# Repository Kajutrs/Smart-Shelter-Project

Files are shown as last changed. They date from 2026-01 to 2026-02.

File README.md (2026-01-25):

ჭკვიანი თავშესაფარი არის კომპლექსური IoT სისტემა, რომელიც შექმნილია ცხოველთა თავშესაფრების ავტომატიზაციისა და რეალურ დროში დისტანციური მონიტორინგისთვის. სისტემა აერთიანებს მაღალი სიმძლავრის თერმულ მართვას და დაბალი დაყოვნების ვიდეო ტრანსლაციას.

---

##  ძირითადი ფუნქციონალი

- **ავტომატური გათბობა:** DHT22 სენსორზე დაფუძნებული ინტელექტუალური თერმორეგულაცია.
- **ობიექტის დეტექცია:** VL53L0X (ToF) სენსორით ცხოველის არსებობის დადგენა მილიმეტრული სიზუსტით.
- **Real-Time Video:** WebRTC ტექნოლოგია წამზე ნაკლები (Sub-second) დაყოვნებისთვის.
- **Cloud Dashboard:** Go-ზე დაწერილი ბექენდი მონაცემთა ვიზუალიზაციისთვის.

---

## ტექნიკური არქიტექტურა

###  აპარატურა (Hardware)
- **MCU:** STM32L476RG (ARM Cortex-M4).
- **მონაცემების გადაცემა:** SIM800C (GSM/GPRS).
- **სენსორები:** - `VL53L0X` (Time-of-Flight) - **I2C ინტერფეისი**.
  - `DHT22` (Temp/Humidity) - **Single-Bus**.
- **კვება:** - `12V 10A` ცენტრალური კვება.
  - `88W` გამათბობელი ფირი.
  - `DROK Step-down` (12V to 5V) სტაბილიზაცია.

### პროგრამული ნაწილი (Software)
- **Firmware:** დაწერილია C-ზე.
- **ბექენდი:** Go (Golang) მაღალი წარმადობისთვის.
- **მედია სერვერი:** MediaMTX (RTSP to WebRTC Gateway).
- **სტრიმინგი:** UDP/SRTP პროტოკოლები.

---

##  ელექტრული პარამეტრები და პროტოკოლები

| კომპონენტი | ინტერფეისი | ძაბვა | დენის ძალა |
| :--- | :--- | :--- | :--- |
| **STM32L4** | Central MCU | 3.3V | < 100mA |
| **SIM800C** | UART | 5V | 2A (Peak) |
| **Heating Pad** | SSR Relay | 12V | **7.33A (88W)** |
| **VL53L0X** | I2C | 3.3V | < 20mA |

---

##  ვიდეო სტრიმინგის ჯაჭვი

1. **Capture:** Tapo C310 კამერა აგენერირებს RTSP ნაკადს.
2. **Gateway:** MediaMTX სერვერი იღებს ნაკადს და ახდენს მის ტრანსმუქსირებას.
3. **Signaling:** SDP (Offer/Answer) და ICE Candidates კავშირის დასამყარებლად.
4. **Latency:** WebRTC უზრუნველყოფს მინიმალურ დაყოვნებას NAT-ის გავლით.

---

##  გუნდი
- **თამარ ჯაში** - მიკროკონტროლერის პროგრამირება, სენსორების ინტეგრაცია და მართვის ალგორითმების შემუშავება.
- **გრიშა ტონერიანი** - სერვერული ინფრასტრუქტურის გამართვა, ვიდეო სტრიმინგის ოპტიმიზაცია და ქსელური კავშირის უზრუნველყოფა.
- **მარი დავლაძე** - ელექტრული სქემების დაპროექტება, ფიზიკური თავშესაფრის აწყობა. 

  ---

##  რეპოზიტორიის შიგთავსი 

ეს რეპოზიტორია შეიცავს პროექტისთვის საჭირო ყველა საკვანძო მასალას:

* ** ნახაზები (Designs):** სისტემის სავარაუდო სქემები და არქიტექტურული ნახაზები.
* ** Excel დოკუმენტაცია:** * **განტის დიაგრამა** (პროექტის ვადები და ფაზები).
    * **ბიუჯეტი & კომპონენტები** (დეტალური ფასები და ლინკები).
    * **მოვალეობების ცხრილი** (გუნდის წევრებს შორის განაწილებული ფუნქციები).
* ** ლიტერატურა:** გამოყენებული წყაროები და მონაცემთა ფურცლები (Datasheets).
* ** სახელმძღვანელო:** მომხმარებლის დეტალური ინსტრუქცია სისტემის გამართვისა და ექსპლუატაციისთვის.
* ** კოდის ნაწყვეტები:** პროექტის ყველაზე კრიტიკული ალგორითმებისა და ფუნქციების იმპლემენტაცია.
* ** პროექტის ვებსაიტი:** ბმული პროექტის შესახებ შექმნილ პლატფორმაზე.

---

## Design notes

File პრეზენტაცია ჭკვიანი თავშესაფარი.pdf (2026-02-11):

ილიას სახელმწიფო უნივერსიტეტი

### დამამთავრებელი კურსის დიზაინის პროექტი A (https://argus.iliauni.edu.ge/ka/student/courses/117972/groups)

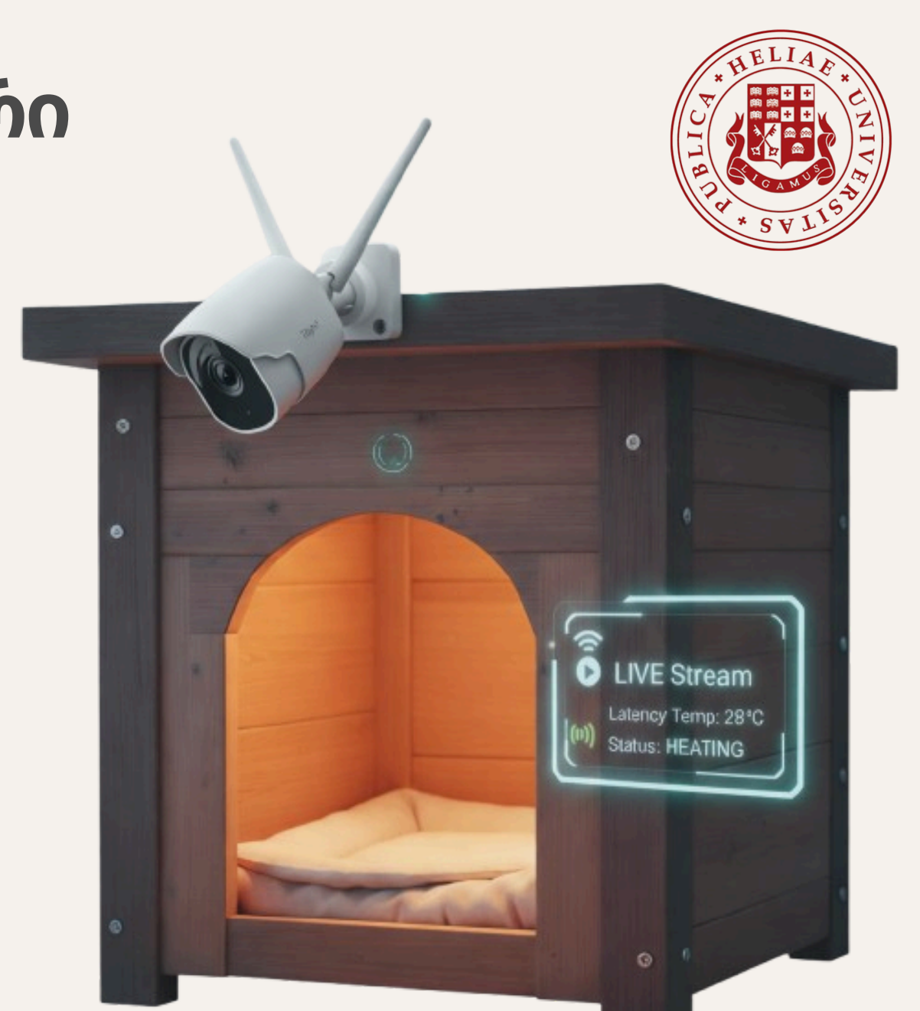
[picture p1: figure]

# ჭკვიანი თავშესაფარი

2026

თამარ ჯაში, გრიშა ტონერიანი,

## მარი დავლაძე

# პრობლემა (1)

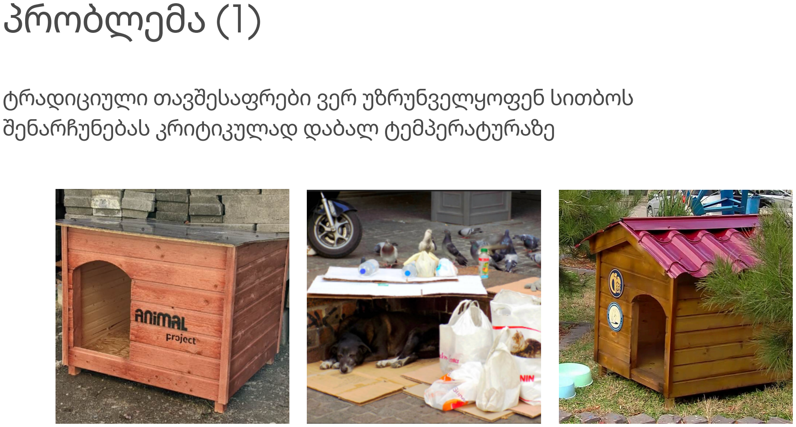
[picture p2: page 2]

### ტრადიციული თავშესაფრები ვერ უზრუნველყოფენ სითბოს შენარჩუნებას კრიტიკულად დაბალ ტემპერატურაზე

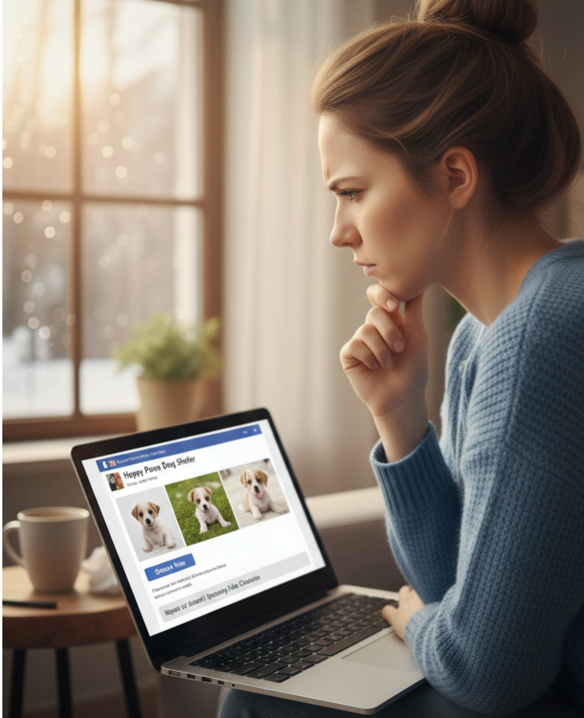
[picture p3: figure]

# პრობლემა(2)

### დონორს არ აქვს საშუალება გადაამოწმოს, რეალურად მიაღწია თუ

არა მისმა დახმარებამ ცხოველამდე.

გ

ა

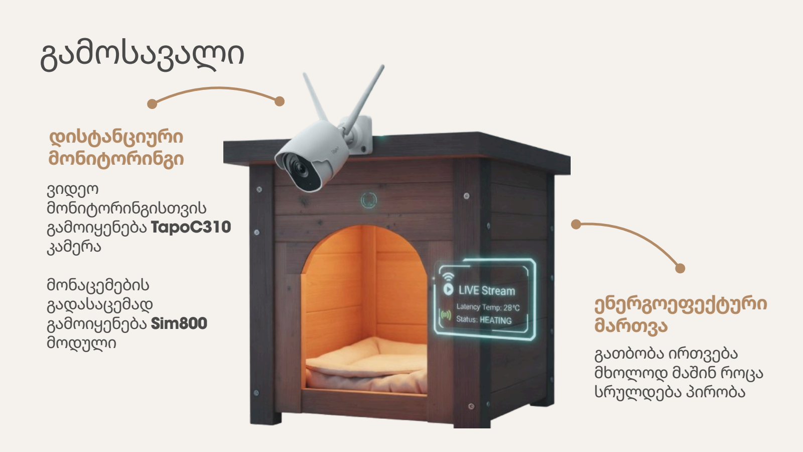
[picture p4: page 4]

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
## ბლოკ - სქემა

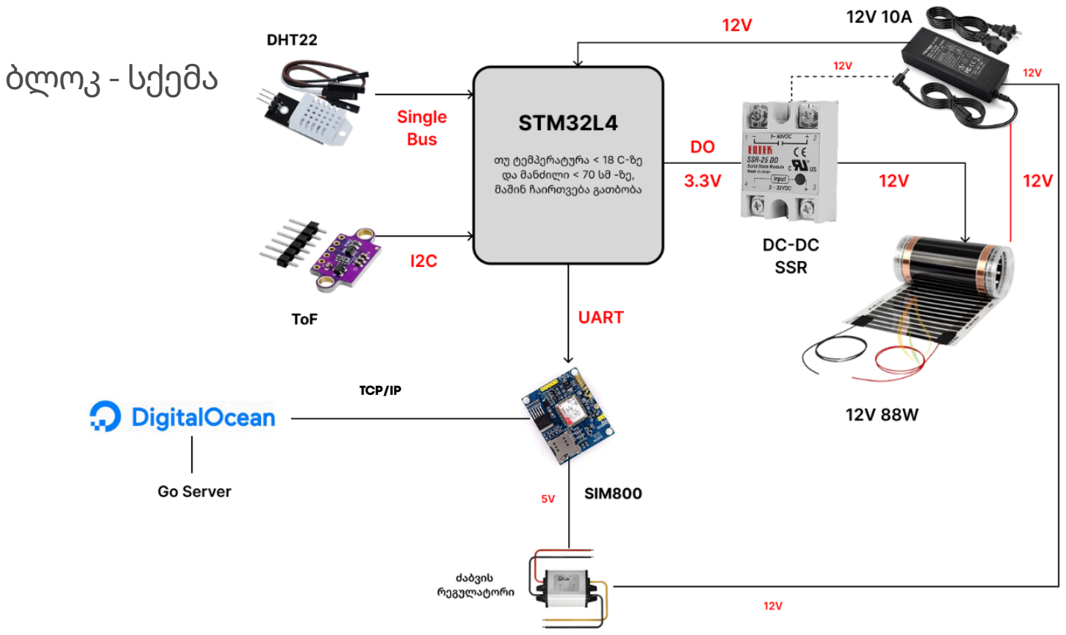
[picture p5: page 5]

TCP/IP

## სისტემის მართვისა და მონაცემთა გადაცემის ალგორითმი

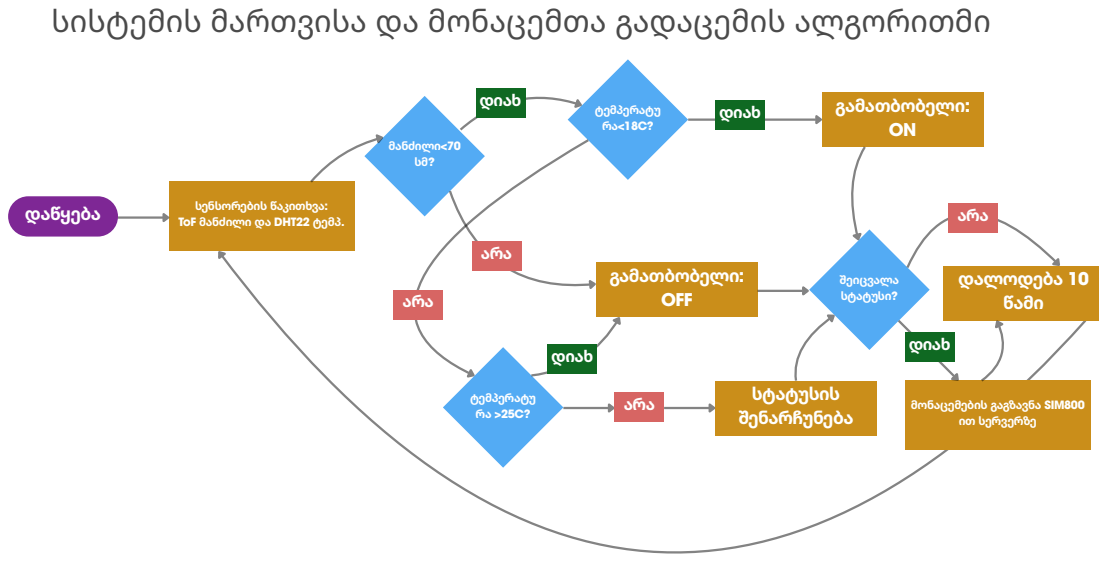
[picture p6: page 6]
მონაცემების გაგზავნა SIM800 ით სერვერზე; გამათბობელი:; დალოდება 10 წამი; სტატუსის შენარჩუნება; მანძილი<70 სმ?; ტემპერატუ რა >25C?; შეიცვალა სტატუსი?; ტემპერატუ რა<18C?; დაწყება; დიახ; არა

დიახ

სენსორების წაკითხვა:
ToF მანძილი და DHT22 ტემპ.

გამათბობელი: | OFF

არა

FPU უზრუნველყოფს სენსორების მონაცემების სწრაფ და ზუსტ
დამუშავებას.

Cortex - M4F

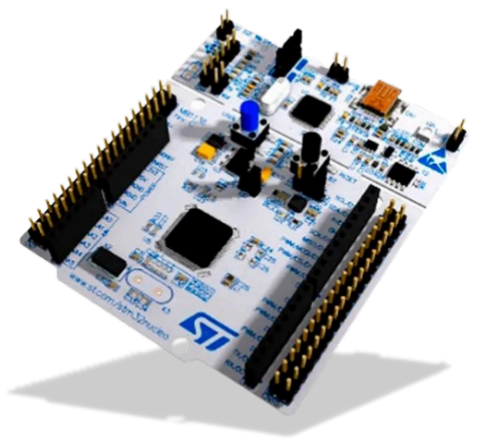
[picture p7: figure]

ენერგოეფექტურობა: L4 სერია

მუშაობს 3.3V ძაბვაზე, რაც თავსებადია სხვა მოწყობილობებთან

როდესაც თავშესაფარი ცარიელია, MCU გადადის Sleep/Stop რეჟიმში ენერგიის მინიმალური
მოხმარებისთვის.

### 3.3 V Logic

# მიკროკონტროლერი

STM32L476RG (https://www.amazon.com/STM32-Nucleo-64-Development-STM32L476RG-NUCLEO-L476RG/dp/B01IO3N646)

# მანძილის სენსორი

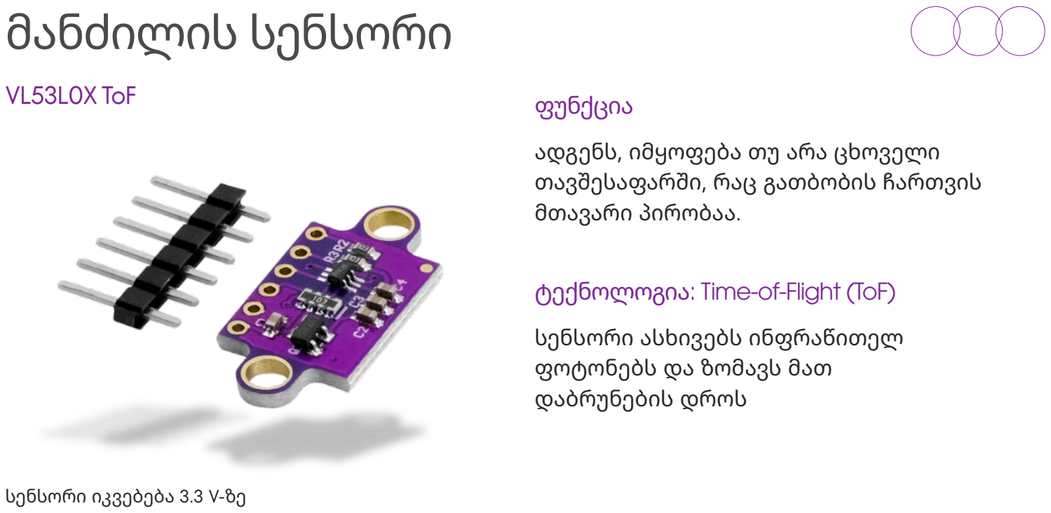
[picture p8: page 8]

ადგენს, იმყოფება თუ არა ცხოველი თავშესაფარში, რაც გათბობის ჩართვის მთავარი პირობაა.

სენსორი ასხივებს ინფრაწითელ ფოტონებს და ზომავს მათ
დაბრუნების დროს

სენსორი იკვებება 3.3 V-ზე

ფუნქცია

ტექნოლოგია: Time-of-Flight (ToF)

### VL53L0X ToF (https://www.temu.com/ul/kuiper/un9.html?subj=goods-un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)

# მანძილის ფორმულა

## D=(c*t)/2

## D- მანძილი C- მუდმივა, სინათლის სიჩქარე(დაახლოებით 3 * 10^8) t- დრო

## 2-ზე გაყოფა საჭიროა, რადგან სინათლემ გაიარა ორმაგი მანძილი - წინ და უკან

# გათბობის ლოგიკა

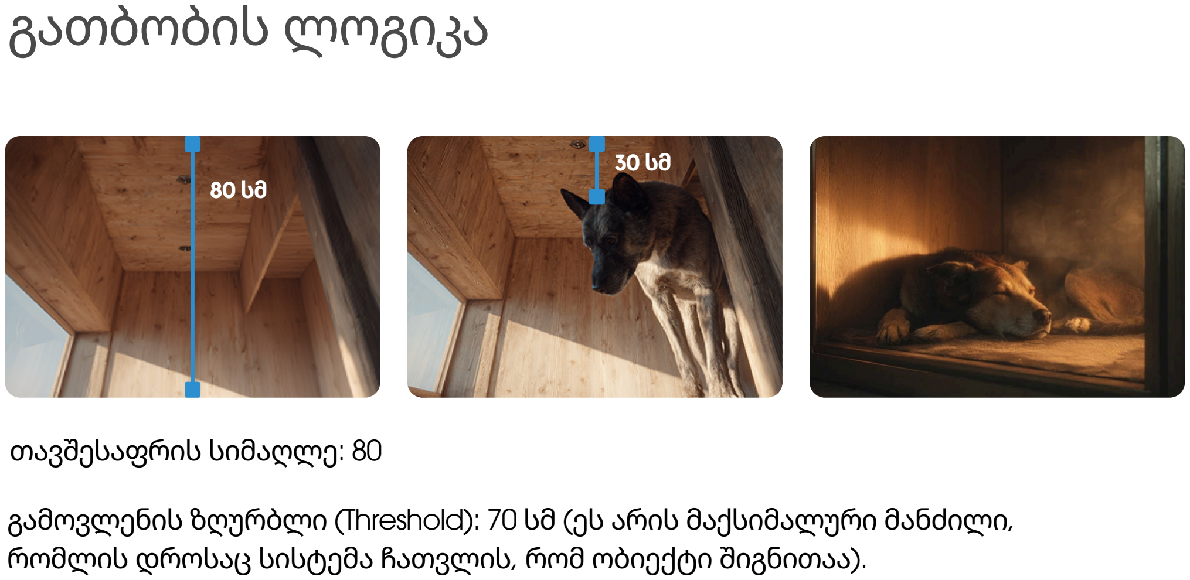
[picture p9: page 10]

### 80 სმ

### 30 სმ

თავშესაფრის სიმაღლე: 80 სმ\ სმtext{ სმ}$.

გამოვლენის ზღურბლი (Threshold): 70 სმ (ეს არის მაქსიმალური მანძილი, რომლის დროსაც სისტემა ჩათვლის, რომ ობიექტი შიგნითაა).

# თერმოსტატული კონტროლი

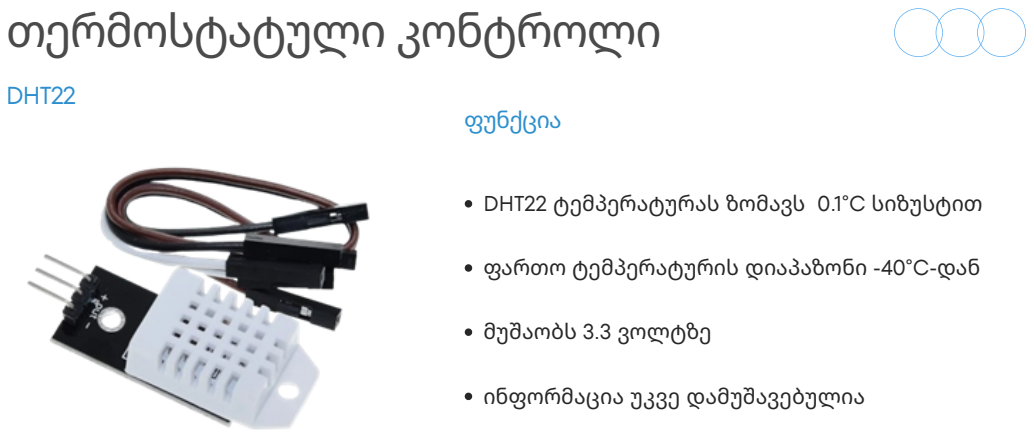
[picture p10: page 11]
ფუნქცია; DHT22; მუშაობს 3.3 ვოლტზე

DHT22 ტემპერატურას ზომავს 0.1°C სიზუსტით

ფართო ტემპერატურის დიაპაზონი -40°C-დან

ინფორმაცია უკვე დამუშავებულია

SIM800C GSM მოდული (https://www.amazon.com/EC-Buying-Quad-Band-Integrated-Transmission/dp/B0B64X81LD)
ფუნქცია

# მონაცემების გადაცემა

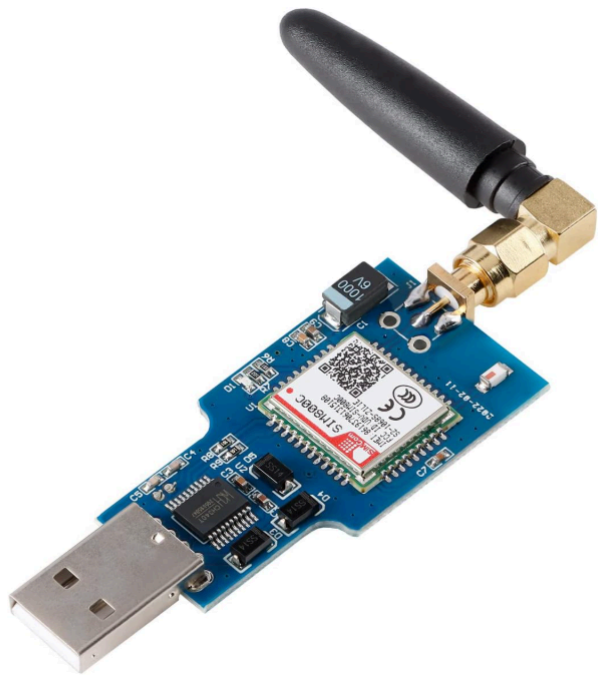
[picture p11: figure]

SIM800C მოდულის მთავარი ფუნქციაა მონაცემთა ტრანსპორტირება. მას შემდეგ, რაც STM32L4 დაამუშავებს სენსორების ინფორმაციას, SIM800C ამ მონაცემებს GPRS არხის მეშვეობით აგზავნის სერვერზე

# გათბობის ფირი

12V Heating Film (https://www.alibaba.com/product-detail/12V-24V-110V-220V-Thermostat-Graphene_60783773014.html) | 12V 10A ადაპტერი
12V

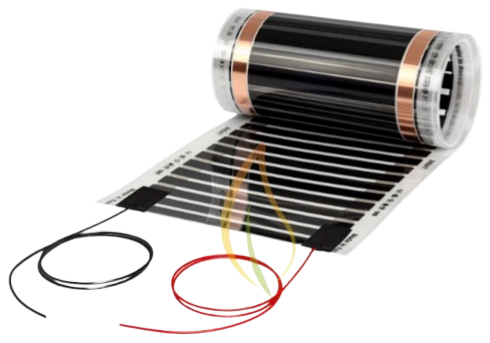
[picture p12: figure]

| 12 ვოლტზე მომუშავე 88 ვატის სიმძლავრის ფირი
| ფირა მაქსიმუმ 45 C - მდე ხურდება

უსაფრთხოების და ძაბვის არჩევანი

# არქიტექტურა და თბოიზოლაცია

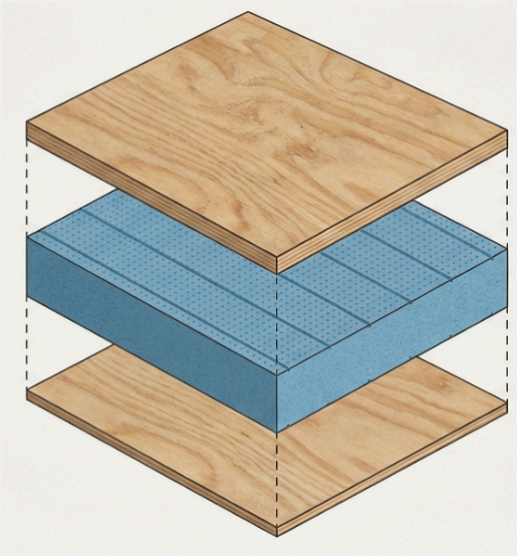
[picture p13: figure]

გარე ფენა

იზოლაცია

შიდა ფენა

12მმ FSF ფანერა

50მმ XPS

8-10 მმ FK ფანერა

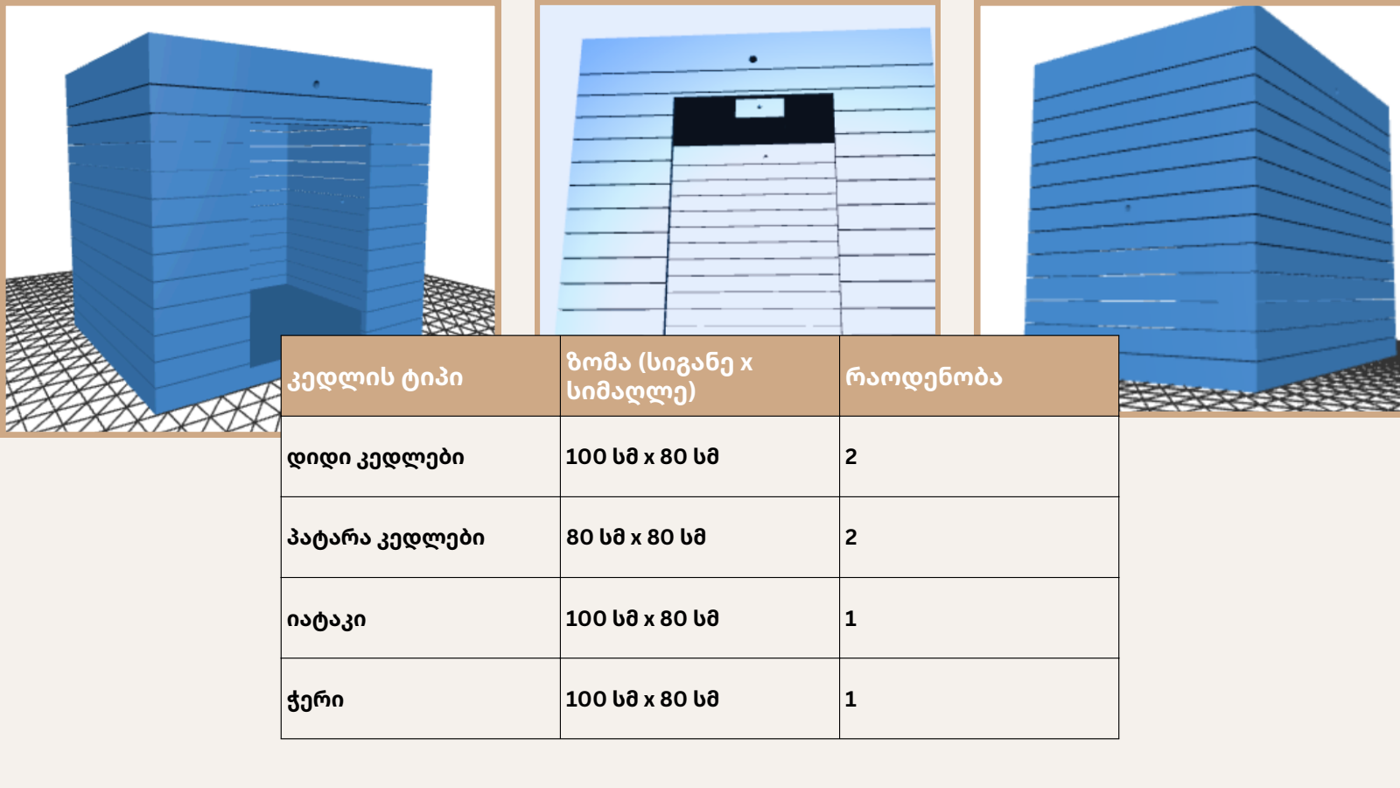
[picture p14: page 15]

კედლის ტიპი | ზომა (სიგანე x სიმაღლე) | რაოდენობა
დიდი კედლები | 100 სმ x 80 სმ | 2
პატარა კედლები | 80 სმ x 80 სმ | 2
იატაკი | 100 სმ x 80 სმ | 1
ჭერი | 100 სმ x 80 სმ | 1

# კამერა

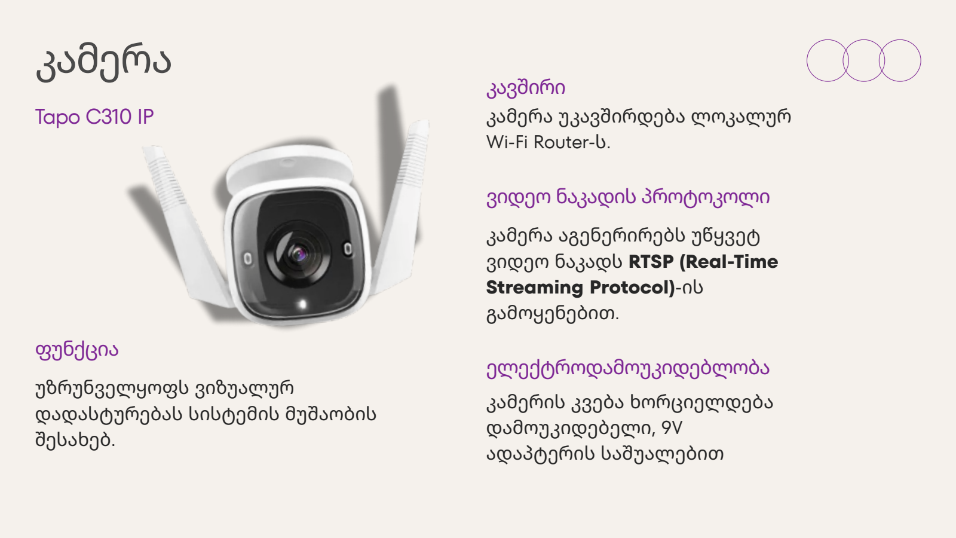
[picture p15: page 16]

უზრუნველყოფს ვიზუალურ
დადასტურებას სისტემის მუშაობის შესახებ.

ფუნქცია

კამერა უკავშირდება ლოკალურ Wi-Fi Router-ს.

კამერა აგენერირებს უწყვეტ
ვიდეო ნაკადს RTSP (Real-Time Streaming Protocol)-ის
გამოყენებით.

კამერის კვება ხორციელდება
დამოუკიდებელი, 9V
ადაპტერის საშუალებით

კავშირი

ვიდეო ნაკადის პროტოკოლი

ელექტროდამოუკიდებლობა

Tapo C310 IP (https://alta.ge/chkviani-kamera/tp-link-tapo-c310-outdoor-security-wi-fi-camera-p22565)

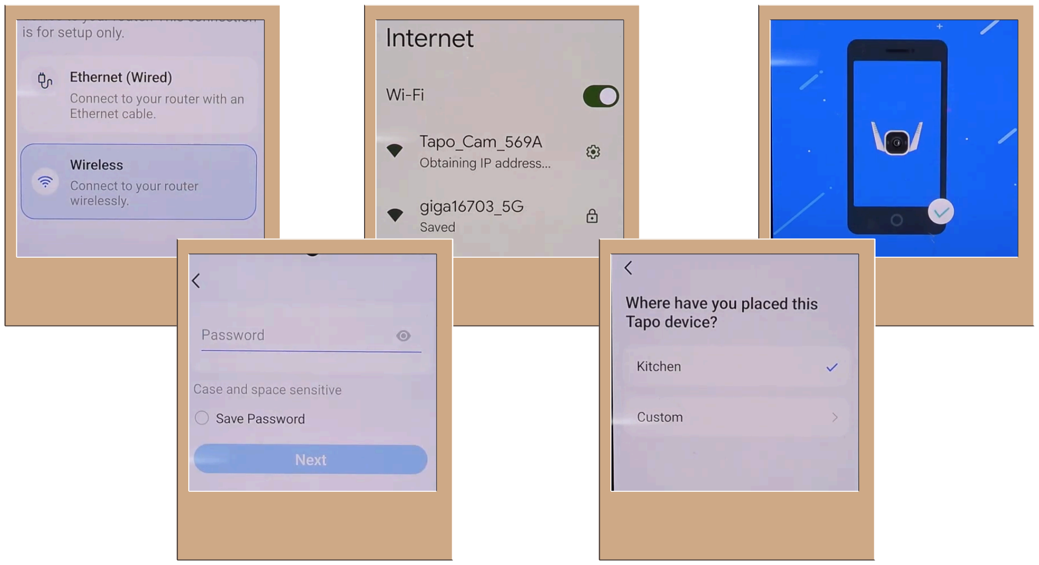
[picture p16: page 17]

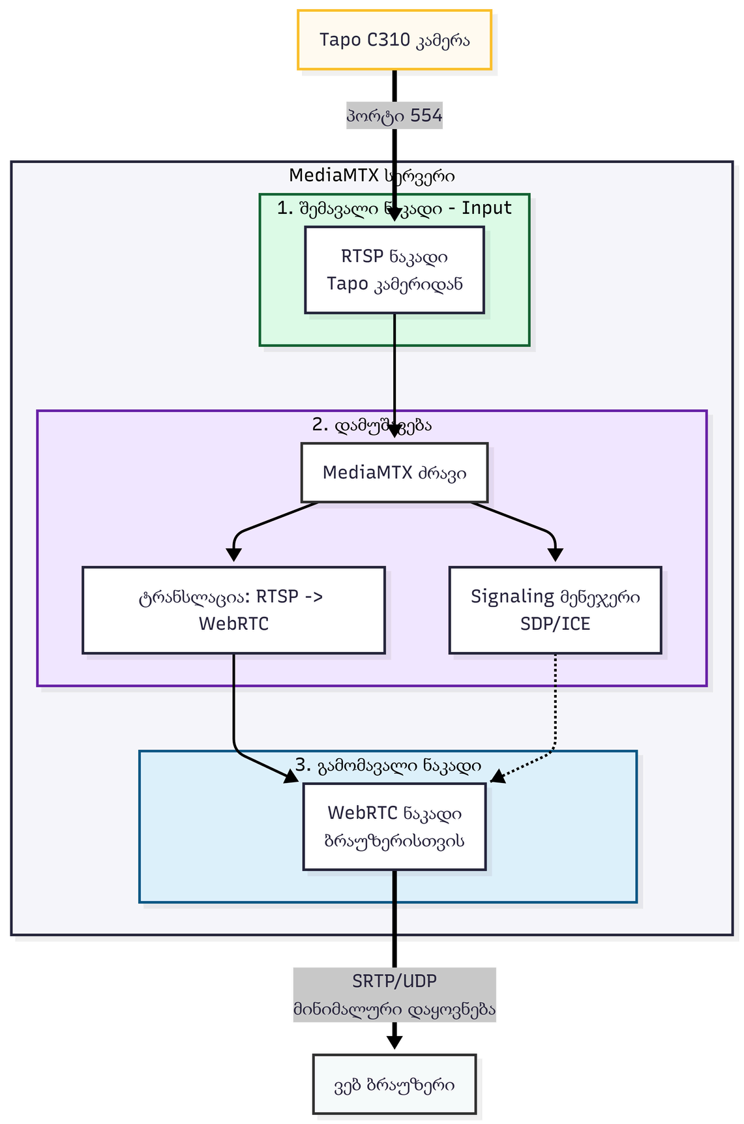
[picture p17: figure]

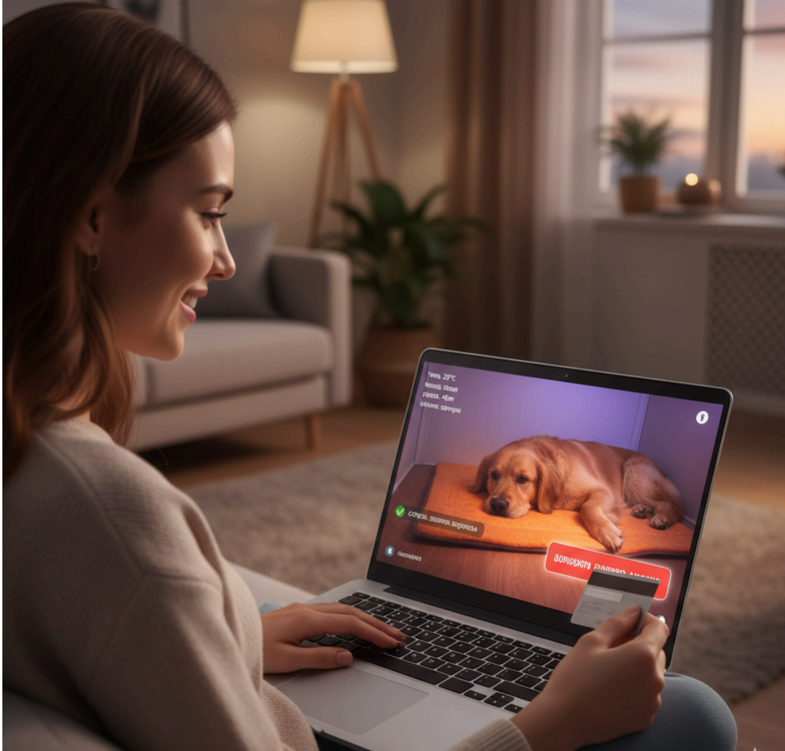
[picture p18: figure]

# დონაცია

გამჭვირვალობა: მომხმარებელი ხედავს ზუსტ ტემპერატურას და ცხოველის მდგომარეობას, რაც ნდობას აჩენს.

ემოციური კავშირი: RTSP
სტრიმინგი საშუალებას აძლევს ადამიანს, გახდეს პროექტის
ნაწილი მსოფლიოს ნებისმიერი წერტილიდან.

განტის დიაგრამა (https://github.com/Kajutrs/Smart-Shelter-Project/blob/main/%E1%83%94%E1%83%A5%E1%83%A1%E1%83%94%E1%83%9A%E1%83%98%E1%83%A1%20%E1%83%A4%E1%83%90%E1%83%98%E1%83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)

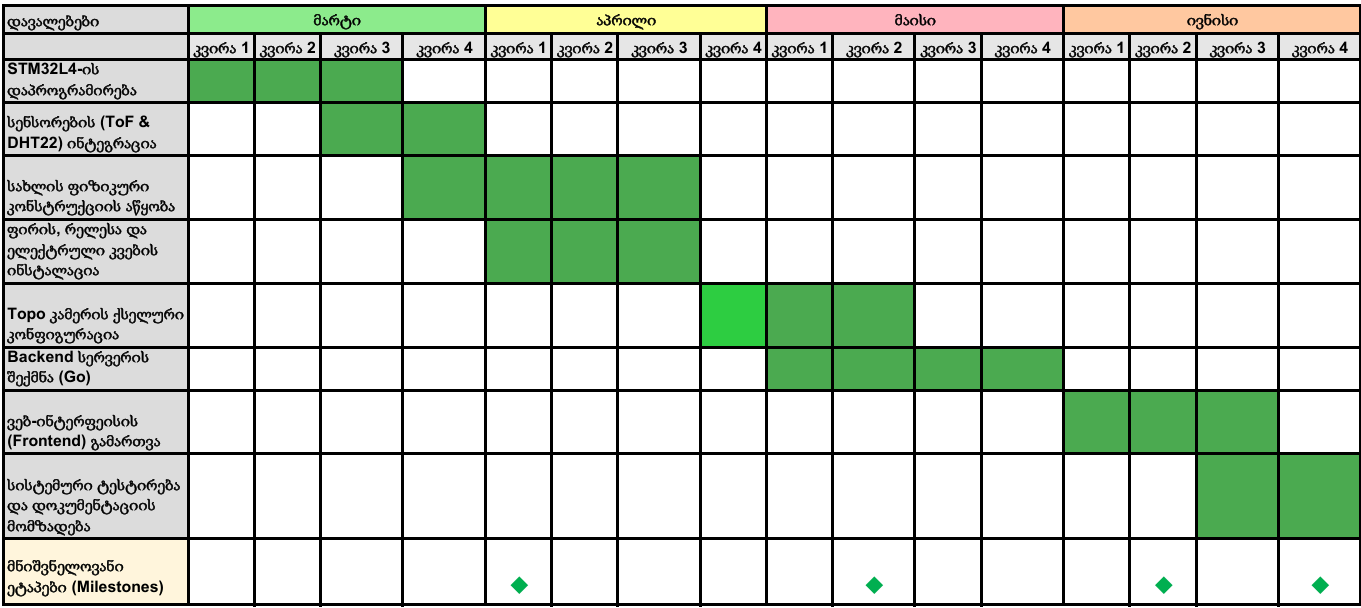
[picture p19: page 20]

მოვალეობები | სტუდენტები
STM32L4 მიკროკონტროლერის დაპროგრამება | თამარ ჯაში
ToF და DHT22 სენსორების ინტეგრაცია | თამარ ჯაში
კომუნიკაციის მოდულის (SIM800C) გამართვა | თამარ ჯაში
თავშესაფრის ფიზიკური აწყობა | მარი დავლაძე
გათბობის ფენის ინსტალაცია | მარი დავლაძე
ელექტრონიკის დაცული განყოფილების მოწყობა | მარი დავლაძე
Tapo კამერის ქსელური კონფიგურაცია | გრიშა ტონერიანი
Backend API-ს დაწერა | გრიშა ტონერიანი
Frontend ინტერფეისის აწყობა | თამარ ჯაში
Digital Ocean სერვერის მომზადება | გრიშა ტონერიანი

კომპონენტები/ბიუჯეტი (https://github.com/Kajutrs/Smart-Shelter-Project/blob/main/%E1%83%94%E1%83%A5%E1%83%A1%E1%83%94%E1%83%9A%E1%83%98%E1%83%A1%20%E1%83%A4%E1%83%90%E1%83%98%E1%83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)

კომპონენტი | ფასი
STM32L476RG | 64.70 ლარი
VL53L0X ToF | 6.29 ლარი
DHT22 | 2.27 ლარი
TP-Link Tapo C310 Wi-Fi | 169 ლარი
SIM800C GSM | 40.09 ლარი
ადაპტერი 12V 10A | 32.81 ლარი
გათბობის ფირი 12V | 12.51 ლარი
რელე DC DC SSR | 6.75 ლარი
Digital Ocean სერვერი | 15.99 ლარი

იხ. სრული სია ლინკზე (https://github.com/Kajutrs/Smart-Shelter-Project/blob/main/%E1%83%94%E1%83%A5%E1%83%A1%E1%83%94%E1%83%9A%E1%83%98%E1%83%A1%20%E1%83%A4%E1%83%90%E1%83%98%E1%83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)

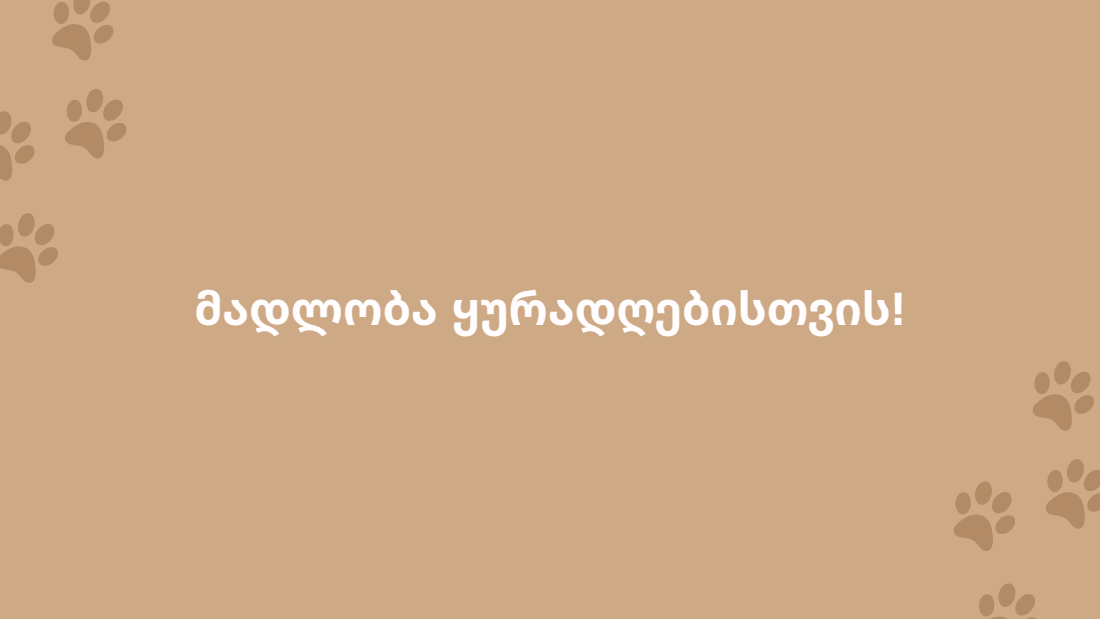
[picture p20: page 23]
მადლობა ყურადღებისთვის!

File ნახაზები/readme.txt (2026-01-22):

1. კლიმატ-კონტროლისა და სენსორული მართვის ბლოკსქემა
ეს სქემა წარმოადგენს სისტემის „ტვინს“ და ასახავს ფიზიკურ კავშირებს მიკროკონტროლერსა და პერიფერიულ მოწყობილობებს შორის

2. სისტემის მართვისა და მონაცემთა გადაცემის ალგორითმი
დიაგრამა აღწერს თავშესაფრის ავტონომიურ სამუშაო ციკლს

3. სისტემის ფუნქციური დიაგრამა და მონაცემთა ნაკადი
ასახავს ინფორმაციის მოძრაობის სრულ ჯაჭვს ლოკალური სენსორებიდან ღრუბლოვან პლატფორმამდე

4. MediaMTX მუშაობის სქემა
ეს დიაგრამა აღწერს ვიზუალური ქვესისტემის მუშაობას, რომელიც დაფუძნებულია დაბალი დაყოვნების ტექნოლოგიებზე

5. RTSP ნაკადის გადაცემა 
ეს დიაგრამა არწერს თუ როგორ შეიძლება Tapo C310 კამერის RTSP ნაკადის გარდაქმნა WebRTC‑ზე MediaMTX - ის გამოყენებით, რათა მომხმარებელს ჰქონდეს პირდაპირი წვდომა ბრაუზერიდან.

6. 3D ფაილი
ეს ფაილი წარმოადგენს „ჭკვიანი თავშესაფრის“ ფიზიკურ მოდელს

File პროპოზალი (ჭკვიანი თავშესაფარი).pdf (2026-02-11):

## ილიას სახელმწიფო უნივერსიტეტი

ბიზნესის, ტექნოლოგიების და განათლების ფაკულტეტი

ტექნოლოგიების სკოლა

# “ჭკვიანი თავშესაფარი”

წინადადება

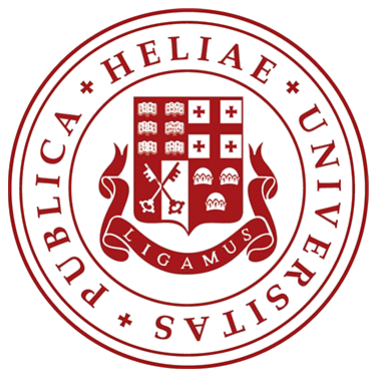
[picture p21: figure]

## გუნდის წევრები

თამარ ჯაში, გრიშა ტონერიანი, მარი დავლაძე

კომპიუტერული ინჟინერიის საბაკალავრო პროგრამა

სენიორ დიზაინის პროექტი A

პროექტის ხელმძღვანელები: პროფ. დავით ჩხაიძე, პროფ. გიორგი მოდებაძე

2026
თბილისი, საქართველო

## სარჩევი

## აბსტრაქტი

მოცემული პროექტი ზამთრის პირობებში, უპატრონო ცხოველთა გადარჩენის აშკარა საჭიროებას IoT-ინტეგრირებული „ჭკვიანი თავშესაფრის“ დაპროექტების გზით გადაჭრის. საინჟინრო თვალსაზრისით, გამოწვევა მდგომარეობს სტატიკური გათბობის სისტემების დაბალ ეფექტურობაში, რაც იწვევს ენერგიის არამიზნობრივ ხარჯვას თავშესაფრის ცარიელ მდგომარეობაში ყოფნისას. პროექტის ფარგლებში შეიქმნება ჰიბრიდული (Hardware & Software) სისტემა, რომლის ძირითადი იდეაა სენსორებზე დაფუძნებული ავტომატური გარემოს მართვა და რეალურ დროში ვიდეომონიტორინგის ინტეგრაცია. ტექნიკური გადაწყვეტა ინოვაციურია Time-of-Flight (ToF) ლაზერული სენსორის გამოყენებით სივრცის მუდმივი სკანირებისთვის, რაც უზრუნველყოფს ობიექტის არსებობის ზუსტ დეტექციას და გამორიცხავს გათბობის სისტემის ფუჭ მუშაობას. მეთოდოლოგია დაეფუძნება STM32L4 მიკროკონტროლერს, SIM800C GSM მოდულსა და სპეციალიზებულ ღრუბლოვან სერვერს მონაცემთა ნაკადების დასამუშავებლად. პროექტის საბოლოო შედეგი იქნება სრულად ფუნქციონალური პროტოტიპი და დისტანციური მონიტორინგის ვებ-პლატფორმა, რომელიც მომხმარებელს რეალურ დროში ვიდეოტრანსლაციის ნახვის, ტელემეტრიული მონაცემების გაცნობისა და ინტეგრირებული დონაციის სისტემით სარგებლობის შესაძლებლობას მისცემს. პროექტის პრაქტიკული და სოციალური მნიშვნელობა კი ცხოველებზე ზრუნვის მდგრადი მოდელის შექმნაში მდგომარეობს, რაც საზოგადოებას ზრუნვის პროცესში გამჭვირვალე ჩართულობის მექანიზმს შესთავაზებს.

## შესავალი

ურბანულ გარემოში უპატრონო ცხოველების გადარჩენა, განსაკუთრებით ზამთრის პერიოდში, სერიოზულ სოციალურ და საინჟინრო გამოწვევას წარმოადგენს. ამ პრობლემის გადასაჭრელად დღეს არსებული მიდგომები მნიშვნელოვან შეზღუდვებს შეიცავს. კერძოდ, პასიური თავშესაფრები ვერ უზრუნველყოფენ ცხოველისთვის საჭირო სითბურ რეჟიმს, ხოლო სტანდარტული აქტიური გათბობის სისტემები მოკლებულია ავტომატიზაციას, რაც ენერგიის არაეფექტურ და არაეკონომიურ ხარჯვას იწვევს. ამასთანავე, არსებული გადაწყვეტილებების ერთ-ერთი უმთავრესი ნაკლოვანება საზოგადოების ჩართულობის მექანიზმების არარსებობაა. ტრადიციული მეთოდები ვერ უზრუნველყოფენ რეალურ დროში მონიტორინგისა და დონაციის გამჭვირვალე სისტემებს. ეს ქმნის ბარიერს მოხალისეებსა და თავშესაფარს შორის, რადგან საზოგადოებას არ აქვს შესაძლებლობა, დისტანციურად დაინახოს თავისი წვლილის შედეგი.

წინამდებარე პროექტი ამ პრობლემას ჭკვიანი IoT ეკოსისტემის დაპროექტებით მოაგვარებს. სისტემა გამოიყენებს STM32 მიკროკონტროლერს, რომელიც სენსორული მონაცემების (ტემპერატურა და მანძილი) ანალიზით მართავს გათბობას მხოლოდ საჭიროების შემთხვევაში. პარალელურად, ვიზუალური მონიტორინგისთვის დაინტეგრირდება მაღალი გარჩევადობის IP კამერა RTSP მხარდაჭერით, რომელიც WiFi ქსელის მეშვეობით გადასცემს ვიდეო ნაკადს, ხოლო WebRTC ტექნოლოგიის გამოყენებით დაინერგება დაბალი დაყოვნების დისტანციური მონიტორინგი. ეს მიდგომა შეესაბამება თანამედროვე Smart City კონცეფციას და IoT ტექნოლოგიების განვითარების გლობალურ ტრენდს, სადაც ურბანული ინფრასტრუქტურა სულ უფრო მეტად ეფუძნება ავტომატიზებულ, მონაცემებზე დაფუძნებულ გადაწყვეტებს. ეს ინოვაციური მიდგომა საინჟინრო გადაწყვეტას (ენერგოეფექტურობა, რეალურ დროში მონაცემთა დამუშავება) გააერთიანებს სოციალურ მიზნებთან, რაც საშუალებას მისცემს ნებისმიერ ადამიანს, ვებსაიტის მეშვეობით გახდეს ზრუნვის პროცესის აქტიური მონაწილე.

პროექტის მიზნები:

- კლიმატ-კონტროლირებადი, ავტომატიზებული თავშესაფრის პროტოტიპის შექმნა.
- რეალურ დროში დისტანციური ვიდეო-მონიტორინგისა და დონაციის ფუნქციონალის დანერგვა.
- ენერგოეფექტური და ავტონომიური მუშაობის უზრუნველყოფა სენსორული ლოგიკის მეშვეობით.

## ნახაზები

მოცემული ნახაზები არ არის საბოლოო სახის და წარმოადგენს პროექტის განვითარების მიმდინარე ეტაპს

1. მოწყობილობის 3D დიზაინი (https://github.com/Kajutrs/Smart-Shelter-Project/blob/main/%E1%83%9C%E1%83%90%E1%83%AE%E1%83%90%E1%83%96%E1%83%94%E1%83%91%E1%83%98/%E1%83%99%E1%83%9D%E1%83%9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)

წარმოდგენილი 3D მოდელი ასახავს პროექტის ფიზიკური თავშესაფრის ძირითად კონსტრუქციას - ზომებს, მასალებს, შესასვლელს და სენსორების განლაგების ადგილებს.

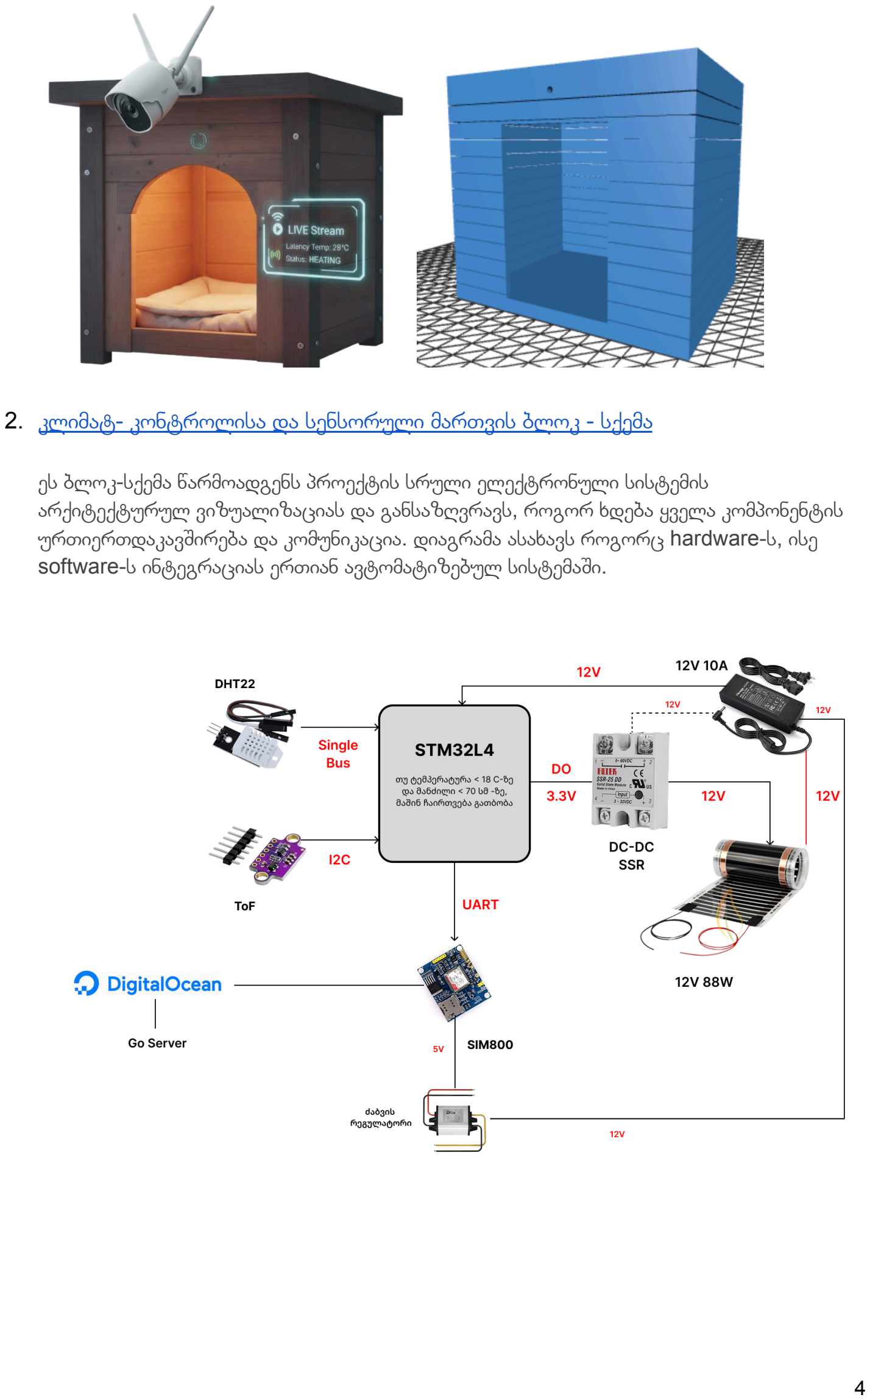
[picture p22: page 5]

2. კლიმატ- კონტროლისა და სენსორული მართვის ბლოკ - სქემა (https://github.com/Kajutrs/Smart-Shelter-Project/blob/main/%E1%83%9C%E1%83%90%E1%83%AE%E1%83%90%E1%83%96%E1%83%94%E1%83%91%E1%83%98/%E1%83%99%E1%83%98%E1%83%9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)

ეს ბლოკ-სქემა წარმოადგენს პროექტის სრული ელექტრონული სისტემის არქიტექტურულ ვიზუალიზაციას და განსაზღვრავს, როგორ ხდება ყველა კომპონენტის ურთიერთდაკავშირება და კომუნიკაცია. დიაგრამა ასახავს როგორც hardware-ს, ისე software-ს ინტეგრაციას ერთიან ავტომატიზებულ სისტემაში.

3. სისტემის მართვისა და მონაცემთა გადაცემის ალგორითმი (https://github.com/Kajutrs/Smart-Shelter-Project/blob/main/%E1%83%9C%E1%83%90%E1%83%AE%E1%83%90%E1%83%96%E1%83%94%E1%83%91%E1%83%98/%E1%83%A1%E1%83%98%E1%83%A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)

ეს დიაგრამა წარმოადგენს პროექტის ცენტრალური მართვის ლოგიკის ვიზუალიზაციას და განსაზღვრავს, როგორ იღებს STM32 მიკროკონტროლერი გადაწყვეტილებებს სენსორული მონაცემების საფუძველზე.

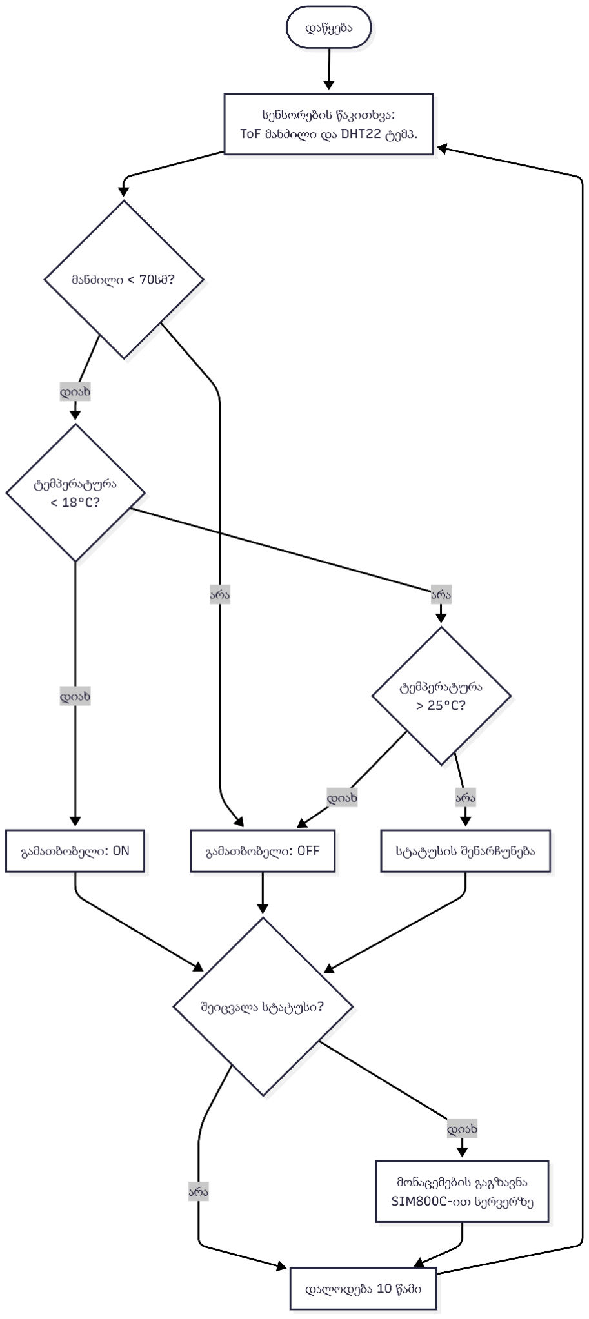
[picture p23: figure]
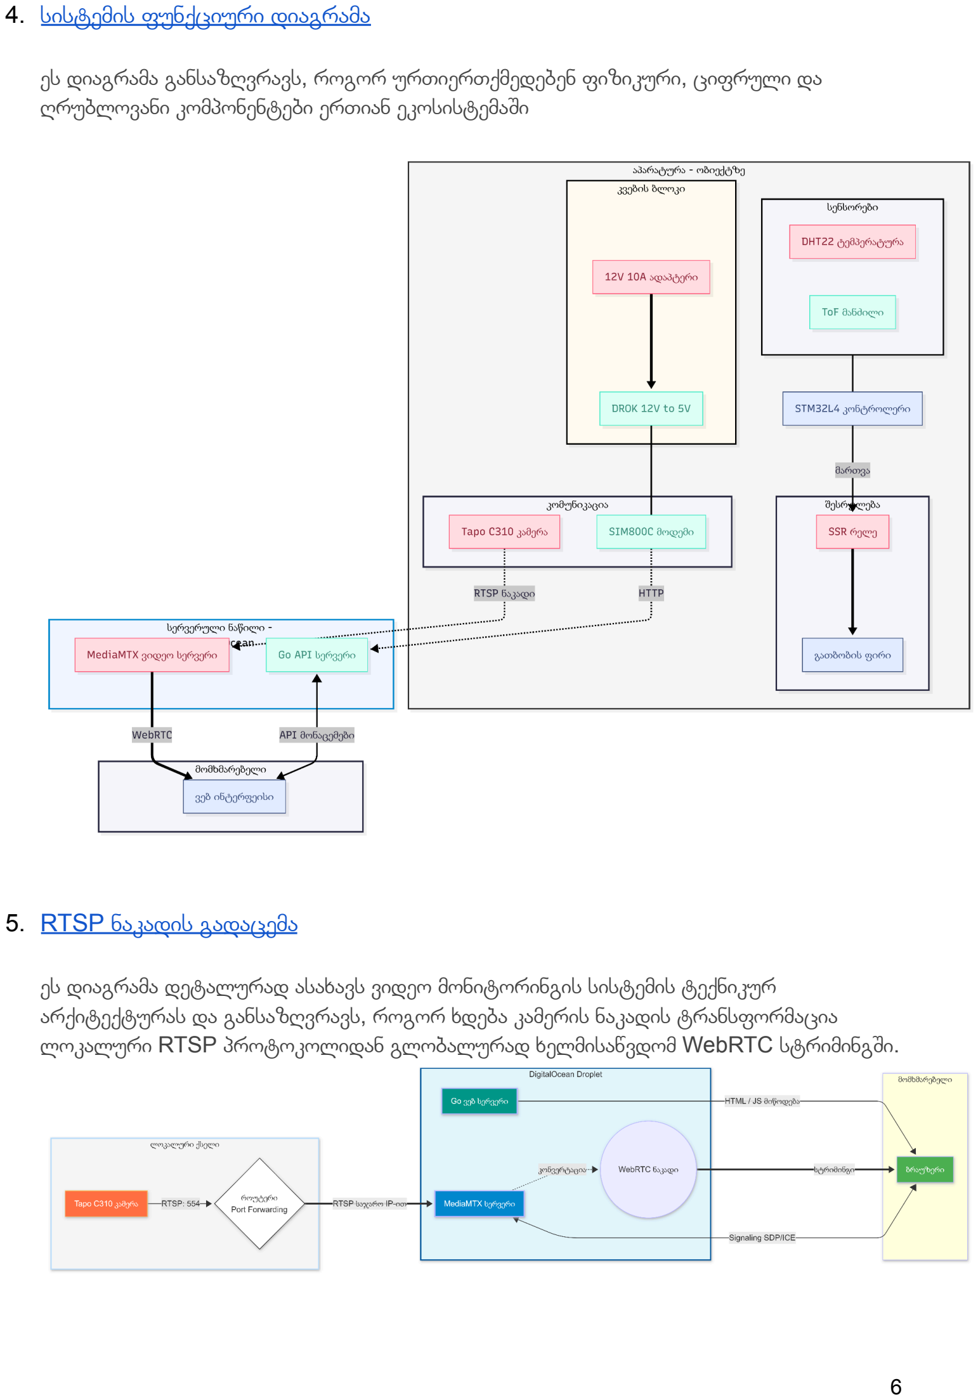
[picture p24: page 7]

4. სისტემის ფუნქციური დიაგრამა (https://github.com/Kajutrs/Smart-Shelter-Project/blob/main/%E1%83%9C%E1%83%90%E1%83%AE%E1%83%90%E1%83%96%E1%83%94%E1%83%91%E1%83%98/%E1%83%A1%E1%83%98%E1%83%A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)

ეს დიაგრამა განსაზღვრავს, როგორ ურთიერთქმედებენ ფიზიკური, ციფრული და ღრუბლოვანი კომპონენტები ერთიან ეკოსისტემაში

5. RTSP ნაკადის გადაცემა (https://github.com/Kajutrs/Smart-Shelter-Project/blob/main/%E1%83%9C%E1%83%90%E1%83%AE%E1%83%90%E1%83%96%E1%83%94%E1%83%91%E1%83%98/RTSP%20%E1%83%9C%E1%83%90%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)

ეს დიაგრამა დეტალურად ასახავს ვიდეო მონიტორინგის სისტემის ტექნიკურ არქიტექტურას და განსაზღვრავს, როგორ ხდება კამერის ნაკადის ტრანსფორმაცია ლოკალური RTSP პროტოკოლიდან გლობალურად ხელმისაწვდომ WebRTC სტრიმინგში.

6. MediaMTX ფუნქციური სქემა (https://github.com/Kajutrs/Smart-Shelter-Project/blob/main/%E1%83%9C%E1%83%90%E1%83%AE%E1%83%90%E1%83%96%E1%83%94%E1%83%91%E1%83%98/MediaMTX%20%E1%83%A4%E1%83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)

ეს დიაგრამა დეტალურად ახსნის MediaMTX სერვერის შიდა მუშაობის პრინციპს.


7. ელექტრული სქემა (გათბობის წრედი) (https://github.com/Kajutrs/Smart-Shelter-Project/blob/main/%E1%83%9C%E1%83%90%E1%83%AE%E1%83%90%E1%83%96%E1%83%94%E1%83%91%E1%83%98/%E1%83%94%E1%83%9A%E1%83%9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)

ეს დიაგრამა დეტალურად ახსნის MediaMTX სერვერის შიდა მუშაობის პრინციპს.


## კოდის ნაწყვეტები

წარმოდგენილია სისტემის ფუნქციონირებისთვის კრიტიკული კოდის ნაწყვეტები

1. დაშბორდის მართვისა და მონაცემთა ინტეგრაციის ლოგიკა (https://github.com/Kajutrs/Smart-Shelter-Project/blob/main/%E1%83%99%E1%83%9D%E1%83%93%E1%83%94%E1%83%91%E1%83%98/%E1%83%93%E1%83%90%E1%83%A8%E1%83%91%E1%83%9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)
ეს არის Go-ს კოდი, რომელიც ჰოსტავს ვებსაიტს (Dashboard), იღებს მონაცემებს და აჩვენებს კამერის ნაკადს
2. მონაცემების გადაცემა (https://github.com/Kajutrs/Smart-Shelter-Project/blob/main/%E1%83%99%E1%83%9D%E1%83%93%E1%83%94%E1%83%91%E1%83%98/%20SIM800C-%E1%83%98%E1%83%A1%20%E1%83%9B%E1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)
კოდის მიზანია SIM800C GSM მოდულის მეშვეობით სენსორული მონაცემების (ტემპერატურა და მანძილი) გაგზავნა დისტანციურ სერვერზე HTTP POST მოთხოვნის გამოყენებით.

3. სერვერის მიმღები (https://github.com/Kajutrs/Smart-Shelter-Project/blob/main/%E1%83%99%E1%83%9D%E1%83%93%E1%83%94%E1%83%91%E1%83%98/%E1%83%A1%E1%83%94%E1%83%9C%E1%83%A1%E1%83%9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)
ეს არის Go (Golang) ენაზე დაწერილი ფუნქცია, რომელიც წინა კოდის (SIM800C-ის) მიერ გაგზავნილი მონაცემების მიმღები მხარეა. ის სერვერზე მუშაობს და ელოდება ინფორმაციას ინტერნეტიდან.
4. STM - ს კონფიგურაცია (https://github.com/Kajutrs/Smart-Shelter-Project/blob/main/%E1%83%99%E1%83%9D%E1%83%93%E1%83%94%E1%83%91%E1%83%98/STM32%20%E1%83%9E%E1%83%98%E1%83%9C%E1%83%94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)
ამ კოდში განსაზღვრულია მიკროკონტროლერის ფიზიკური კავშირი გარე მოწყობილობებთან. კოდი ახდენს პინების ფუნქციურ დეკლარირებას, რაც უზრუნველყოფს სისტემის მოქნილობას და მართვადობას
5. ჭკვიანი თავშესაფრის ცენტრალური მართვის ალგორითმი (https://github.com/Kajutrs/Smart-Shelter-Project/blob/main/%E1%83%99%E1%83%9D%E1%83%93%E1%83%94%E1%83%91%E1%83%98/%E1%83%AD%E1%83%99%E1%83%95%E1%83%98%E1%83%9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)
პროპოზალში ეს ნაწილი წარმოადგენს სისტემის ინტელექტუალურ ბირთვს, რომელიც მუშაობს STM32L476RG მიკროკონტროლერზე. მისი მუშაობა დაყოფილია სამ ფაზად: 1. ინიციალიზაცია და კავშირის დამყარება, 2. გადაწყვეტილების მიღების ლოგიკა, 3. გლობალური ტელემეტრია.
6. TapoC310 ვიდეო ნაკადი (RTSP) (https://github.com/Kajutrs/Smart-Shelter-Project/blob/main/%E1%83%99%E1%83%9D%E1%83%93%E1%83%94%E1%83%91%E1%83%98/Tapo%20C310%20%E1%83%95%E1%83%98%E1%83%93%E1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)
ეს კოდი წარმოადგენს სერვერულ მოდულს, რომელიც უზრუნველყოფს მოწყობილობიდან გამოგზავნილი ტელემეტრიული მონაცემების მიღებას, დამუშავებასა და სისტემატიზაციას.
7. მართვის ალგორითმი (https://github.com/Kajutrs/Smart-Shelter-Project/blob/main/%E1%83%99%E1%83%9D%E1%83%93%E1%83%94%E1%83%91%E1%83%98/%E1%83%9B%E1%83%90%E1%83%A0%E1%83%97%E1%83%9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)
ეს კოდი წარმოადგენს გადაწყვეტილების მიღების ალგორითმს, რომელიც რეალურ დროში მართავს სისტემის ფიზიკურ რეაგირებას სენსორებიდან მიღებული მონაცემების საფუძველზე

GitHub - ის რეპოზიტორიის ლინკი, სადაც განთავსებულია კოდის ნაწყვეტები ნახაზები, ვებსაიტის ლინკი, პრეზენტაცია, ბიუჯეტი, განტის დიაგრამა, მოხმარების სახელმძღვანელო და პროექტში გამოყენებული ლიტერატურა - Smart Shelter Project (https://github.com/Kajutrs/Smart-Shelter-Project/tree/main)

## მორგებული თავები

## 1. არქიტექტურა და კონსტრუქცია

პროექტის ფიზიკური სტრუქტურა ეფუძნება "High-Efficiency Sandwich Panel" კონცეფციას, სადაც თითოეული ელემენტი გათვლილია მაქსიმალურ თბოიზოლაციაზე, გამძლეობასა და ცხოველის კომფორტზე.

### 1.1 კედლებისა და იატაკის სტრუქტურა

სახლის ყველა კედელი, იატაკი და ჭერი წარმოადგენს სამშრიან სისტემას:

გარე ფენა: 12 მმ-იანი FSF ფანერა. შერჩეულია მისი მაღალი ნესტგამძლეობისა და გარემო პირობებისადმი (წვიმა, თოვლი) გამძლეობის გამო.

საიზოლაციო ბირთვი: 50 მმ-იანი XPS (ექსტრუდირებული პოლისტიროლი). ეს მასალა


გამოირჩევა დაბალი თბოგამტარობით და არ იწოვს ტენს, რაც უზრუნველყოფს სახლში სითბოს შენარჩუნებას ზამთრის პერიოდში.

შიდა ფენა: 8-10 მმ-იანი FK ფანერა. ის არის ეკოლოგიურად სუფთა მასალა, რომელიც ქმნის მყუდრო და უსაფრთხო გარემოს შინაური ცხოველისთვის.

### 1.2 ელექტრონიკის დაცული განყოფილება

იმისათვის, რომ სისტემა იყოს დაცული და სადენები არ იყოს ხელმისაწვდომი ცხოველისთვის:

- უკანა კედლის შიდა ნაწილში, საიზოლაციო (XPS) შრეში, ამოჭრილია სპეციალური ღრუ (150x100 მმ). აქ თავსდება წყალგაუმტარი ყუთი, რომელშიც მოთავსებულია მთელი ელექტრონიკა.
- გარე კედელზე განთავსებულია 24 მმ-იანი ხვრელი, საიდანაც 12V 8A ადაპტერი უერთდება სისტემას. ეს უზრუნველყოფს კვების ბლოკის გარეთ დარჩენას (უკეთესი


გაგრილებისთვის) და სახლში მხოლოდ უსაფრთხო ძაბვის შეყვანას.

### 1.3 კონსტრუქციული ზომები და პარამეტრები

პროექტის დაგეგმვისას ჩვენი მთავარი მიზანი იყო შეგვექმნა უნივერსალური პლატფორმა, რომელშიც კომფორტულად მოთავსდება ნებისმიერი შერჩეული ზომის შინაური ცხოველი — იქნება ეს კატა თუ სხვადასხვა ჯიშის ძაღლი. სწორედ ამიტომ, კონსტრუქცია საშუალო და დიდი ზომის ძაღლების პარამეტრებზე გავთვალეთ, რათა სივრცე ყოფილიყო მაქსიმალურად ტევადი და ადაპტირებადი.

ძირითადი პარამეტრები (სანტიმეტრებში):

კედლის ტიპი | ზომა (სიგანე x სიმაღლე) | რაოდენობა
დიდი კედლები | 100 სმ x 80 სმ | 2
პატარა კედლები | 80 სმ x 80 სმ | 2
იატაკი | 100 სმ x 80 სმ | 1
ჭერი | 100 სმ x 80 სმ | 1

მოწყობილობის 3D დიზაინი (https://github.com/Kajutrs/Smart-Shelter-Project/blob/main/drawings/%E1%83%99%E1%83%9D%E1%83%9C%E1%83%A1%E1%83%A2%E1%83%A0%E1%83%A3%E1%83%A5%E1%83%AA%E1%83%98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)

## 2. ელექტრონული სისტემა და კვება

ჩვენი მიზანი იყო შეგვექმნა საიმედო, უსაფრთხო და მაღალი წარმადობის მართვის ცენტრი.

### 2.1 ცენტრალური მართვის ბლოკი (STM32)

სისტემის "ინტელექტუალურ ცენტრს" წარმოადგენს STM32L476RG მიკროკონტროლერი, რომელიც დაფუძნებულია მძლავრ ARM Cortex-M4F ბირთვზე[1, სექ. 3.1]. პროექტისთვის ამ კონკრეტული მოდელის შერჩევა რამდენიმე კრიტიკულმა ფაქტორმა განაპირობა:

- Ultra-Low-Power (ULP) არქიტექტურა: მიკროკონტროლერი გამოირჩევა ენერგიის
მოხმარების მინიმალური მაჩვენებლებით, რაც
FlexPowerControl ტექნოლოგიის დამსახურებაა [1,


p. 1]. ის საშუალებას გვაძლევს გამოვიყენოთ ენერგიის დაზოგვის სპეციალური რეჟიმები, როგორიცაა Stop 2 (მოხმარება 1.1 µA) და Standby (მოხმარება 120 nA) [1, ცხრილი 4]. ეს კრიტიკულია იმისათვის, რომ პასიურ მდგომარეობაში სისტემამ პრაქტიკულად არ მოიხმაროს ელექტროენერგია, რაც პროექტს მაღალ ენერგოეფექტურობას სძენს.
- FPU (Floating Point Unit) მხარდაჭერა:მიკროკონტროლერი აღჭურვილია მცოცავმძიმიანი გამოთვლების ერთეულით, რომელიც სრულად უჭერს მხარს IEEE 754 სტანდარტს [1, სექ. 3.1]. FPU-ს არსებობა საშუალებას გვაძლევს განვახორციელოთ რთული მათემატიკური ოპერაციები აპარატურულ დონეზე, რაც ამცირებს პროცესორის დატვირთვას და ზრდის სისტემის რეაგირების სისწრაფეს [1, გვ. 1]
- ეფექტური პერიფერიული მართვა: STM32L476RG სტაბილურად მართავს ყველა გარე მოწყობილობას (როგორც სენსორებს, ისე რელეს) 3.3V ძაბვით.
- ავტონომიური კონტროლი: სისტემა მუშაობს სრულად ავტონომიურ რეჟიმში. ის დამოუკიდებლად აანალიზებს გარემო პირობებს და იღებს გადაწყვეტილებებს, რაც უზრუნველყოფს მთლიანი კომპლექსის მაქსიმალურ საიმედოობასა და ენერგოეფექტურობას.

პერიფერიული მოწყობილობების პინების კონფიგურაცია (https://github.com/Kajutrs/Smart-Shelter-Project/blob/main/src/STM32%20Configuration%20Snippet%20(C))

ჭკვიანი თავშესაფრის ცენტრალური მართვის ალგორითმი (https://github.com/Kajutrs/Smart-Shelter-Project/blob/main/src/main.c)

### 2.2 კვების სისტემა და ენერგიის მართვა

სისტემის კვების ბლოკი დაფუძნებულია ცენტრალიზებულ 12V 10A (120W) AC/DC ადაპტერზე. აღნიშნული სიმძლავრე შერჩეულია იმ გათვლით, რომ სისტემამ შეძლოს პიკურ დატვირთვაზე მუშაობა (გათბობის ელემენტის აქტივაციის მომენტში) ძაბვის ვარდნის გარეშე. 12V ძაბვა წარმოადგენს ოპტიმალურ ბალანსს უსაფრთხოებასა და სიმძლავრეს შორის: ის პირდაპირ კვებავს გათბობის სისტემას, რაც გამორიცხავს დამატებითი მძლავრი ინვერტორების საჭიროებას და ამცირებს სისტემის თვითღირებულებას.

## 3. სენსორული სისტემა და მონაცემთა დამუშავება/გადაცემა

მოცემულ თავში დეტალურად არის განხილული ის ინტეგრირებული ტექნოლოგიური კომპონენტები და სენსორული მოდულები, რომლებიც სისტემის
ავტონომიურ ფუნქციონირებასა და გარემო პირობებზე გონივრულ რეაგირებას უზრუნველყოფენ

### 3.1 VL53L0X - Time-of-Flight (ToF) მანძილის სენსორი

მანძილის ეს სენსორი პასუხისმგებელია ობიექტის აღმოჩენაზე.

- ტექნოლოგია: ტრადიციული ულტრაბგერითი სენსორებისგან განსხვავებით, ToF იყენებს უხილავ ლაზერულ იმპულსს. იგი ზომავს დროს, რომელიც სჭირდება სინათლეს ობიექტამდე მისასვლელად და უკან დასაბრუნებლად.
- სიზუსტე: სენსორი მუშაობს მილიმეტრული სიზუსტით. მისი მთავარი უპირატესობაა შედეგის დამოუკიდებლობა ობიექტის არეკვლის უნარზე (Target reflectance), რაც კრიტიკულია სხვადასხვა ფერის ბეწვის მქონე ცხოველების დასაფიქსირებლად [2, გვ. 1].
- პროგრამული ლოგიკა: STM32L476RG მიკროკონტროლერი სენსორთან კომუნიკაციას ახორციელებს I2C პროტოკოლით [2, გვ. 1]. ალგორითმი ითვალისწინებს 70 სმ-იან ზღურბლს: თუ დაფიქსირებული მანძილი ამ მაჩვენებელზე ნაკლებია, სისტემა ადასტურებს ცხოველის ყოფნას თავშესაფარში.

### 3.2 DHT22 – ტემპერატურის კონტროლი

ტემპერატურის კონტროლისთვის გამოყენებულია მაღალი სიზუსტის DHT22 სენსორი.

- ფუნქცია: AM2302(ბაზარზე ცნობილი, როგორც DHT22) სენსორის მთავარი ფუნქციაა გარემო პირობების მუდმივი კონტროლი და გათბობის სისტემის მართვისთვის საჭირო ზუსტი მონაცემების მიწოდება. მისი მუშაობა შემდეგ კონკრეტულ ეტაპებად იყოფა:
- მონაცემთა შეგროვება: სენსორი ზომავს ტემპერატურასა და ტენიანობას მაღალი სიზუსტით (±0.5C°), რაც აუცილებელია ცხოველისთვის კომფორტული 18°C-25°C დიაპაზონის შესანარჩუნებლად [5, გვ. 2].

ელექტრული ხარვეზების დროს [5,

- ავტომატური გადამოწმება: ყოველი
გაზომვისას სენსორი იყენებს
„საკონტროლო ჯამს“ (Checksum),
რათა დარწმუნდეს, რომ ინფორმაცია სწორია. ეს ფუნქცია გამორიცხავს სისტემის შეცდომით ჩართვას
- აქტივაცია: თუ ToF სენსორი
ადასტურებს ცხოველის ყოფნას და შიდა ტემპერატურა ჩამოცდება 18°C-ს, STM32 გასცემს ბრძანებას რელეს ჩართვაზე და იწყება გათბობის პროცესი.
- დეაქტივაცია: ენერგოეფექტურობისა და ცხოველის კომფორტისთვის, როგორც კი ტემპერატურა მიაღწევს 25°C-ს, სისტემა ავტომატურად თიშავს გათბობას.

### 3.3 SIM800C GSM მოდული

პროექტის ავტონომიურობისთვის ვიყენებთ SIM800C GSM მოდულს, რომელიც საშუალებას გვაძლევს, სენსორების მონაცემები ინტერნეტით ნებისმიერი ადგილიდან გადავცეთ Go სერვერს. მოდული STM32-თან დაკავშირებულია UART ინტერფეისით.

- ინტერფეისი: მოდული STM32L4 მიკროკონტროლერთან დაკავშირებულია UART პროტოკოლით, რაც მონაცემთა საიმედო ცვლას განაპირობებს.


- ენერგიის მართვა: მონაცემთა გადაცემის პროცესში მოდული საჭიროებს 2.0A პიკურ დენს. აღნიშნული მოთხოვნა დაკმაყოფილებულია DROK Buck-კონვერტორის საშუალებით, რომელიც 12V ძაბვას გარდაქმნის სტაბილურ 5V 3A (15W) გამოსავლად
- მონაცემების გაგზავნა: მას შემდეგ, რაც მიკროკონტროლერი UART-ის საშუალებით JSON-პაკეტს მოდემის შიდა ბუფერში განათავსებს, ეს ბრძანება SIM800C-ს აიძულებს, გახსნას TCP/IP კავშირი მითითებულ IP მისამართთან, მოახდინოს HTTP ჰედერების ფორმირება და ბუფერში არსებული ინფორმაცია POST მეთოდით გადასცეს სერვერს.

ტელემეტრიული მონაცემების გაგზავნა HTTP POST მეთოდით (C) (https://github.com/Kajutrs/Smart-Shelter-Project/blob/main/src/Data%20Transmission%20Snippet)

სენსორული მონაცემების მიმღები ფუნქცია (Go) (https://github.com/Kajutrs/Smart-Shelter-Project/blob/main/src/Go%20Server%20Handler%20%28Go%29)

## 4. ვიდეო მონიტორინგი და ქსელური ინფრასტრუქტურა

პროექტის ფუნდამენტურ კომპონენტს წარმოადგენს დისტანციური ვიზუალური მონიტორინგის სისტემა, რისთვისაც იმპლემენტირებულია სრული ტექნოლოგიური სტეკი. აღნიშნული ინფრასტრუქტურა უზრუნველყოფს ლოკალური ვიდეო ნაკადის ტრანსფორმაციასა და სტაბილურ ტრანსლაციას გლობალურ ქსელში.

### 4.1 აპარატურული საფუძველი და კავშირი

- Tapo Camera: სისტემის ვიზუალურ წყაროდ შერჩეულია Tapo-ს ჭკვიანი კამერა, რომელიც მხარს უჭერს მაღალი გარჩევადობის ვიდეოს და RTSP (Real Time Streaming Protocol) პროტოკოლს.


- ავტონომიური კვება: კამერის კვება ხორციელდება დამოუკიდებლად, კომპლექტაციაში არსებული ინდივიდუალური 9V ადაპტერის საშუალებით. ეს მიდგომა უზრუნველყოფს ვიდეო სისტემის სრულ ელექტრულ იზოლაციას ძირითადი 12V 10A მაგისტრალისგან
- სისტემური საიმედოობა: ვინაიდან კამერა არ იტვირთავს საერთო კვების ბლოკს, მთლიანი 120W სიმძლავრე სრულად ნაწილდება გათბობის სისტემასა (88W) და IoT მოდულზე, რაც ზრდის სისტემის მდგრადობას და შეესაბამება IEC 62368-1 უსაფრთხოების სტანდარტს
- ქსელური კავშირი და დისტანციური წვდომა: გარე სამყაროდან კამერასთან წვდომის მისაღებად, ლოკალურ როუტერზე გაიწერება პორტების გადამისამართების (Port Forwarding) წესები, რაც აუცილებელია RTSP ნაკადის სერვერამდე მისასვლელად:
1. RTSP მხარდაჭერა: კამერა უზრუნველყოფს ვიდეო ნაკადის გადაცემას სტანდარტული RTSP პროტოკოლით, რაც აუცილებელია გარე სერვერთან ინტეგრაციისთვის [3, გვ. 6].
2. TCP/IP კომუნიკაცია: მონაცემთა გადასაცემად გამოიყენება TCP/IP და UDP პროტოკოლები, რაც უზრუნველყოფს თავსებადობას ქსელურ ფაირვოლებთან [3,
გვ. 6].

### 4.2 სერვერული არქიტექტურა (Digital Ocean & MTX)

ვიდეო ნაკადის დამუშავება და მომხმარებლამდე მიწოდება ხდება ღრუბლოვანი ტექნოლოგიების გამოყენებით

Digital Ocean Droplet: სისტემის Backend და მედია სერვერი განთავსებულია Digital Ocean-ის ვირტუალურ სერვერზე.

- MediaMTX (MTX) სერვერი: სერვერზე გაშვებულია MediaMTX მედია სერვერი[4]. იგი ასრულებს "შუამავლის" როლს: იღებს RTSP ნაკადს კამერიდან და ახდენს მის კონვერტაციას WebRTC ფორმატში, რათა ვიდეო პირდაპირ ბრაუზერში, დამატებითი პლაგინების გარეშე გაეშვას.

### 4.3 პროგრამული უზრუნველყოფა (Go & Frontend)

- Go Backend: ვებ-სერვერი დაწერილია Go (Golang) ენაზე. ეს არჩევანი განპირობებულია Go-ს მაღალი წარმადობითა და ქსელურ პროტოკოლებთან მუშაობის ეფექტურობით. ვებ-სერვერი მართავს API მოთხოვნებს, ახორციელებს კამერის სტატუსის მუდმივ მონიტორინგს და უზრუნველყოფს მონაცემთა უსაფრთხო მიმოცვლას მედია სერვერსა და კლიენტს შორის.

Dashboard-ის მართვისა და მონაცემთა ინტეგრაციის ლოგიკა (Go) (https://github.com/Kajutrs/Smart-Shelter-Project/blob/main/src/Backend%20%E1%83%A1%E1%83%94%E1%83%A0%E1%83%95%E1%83%94%E1%83%A0%E1%83%98%20%E1%83%93%E1%83%90%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)

Go Backend სერვერის მთავარი ლოგიკა (https://github.com/Kajutrs/Smart-Shelter-Project/blob/main/src/server.go)

- Frontend ინტერფეისი: მომხმარებლისთვის შეიქმნება თანამედროვე ვებ-გვერდი, სადაც ინტეგრირებული იქნება ვიდეო პლეერი ლაივ სტრიმინგისთვის.
- ინტეგრირებული საქველმოქმედო მოდული (Donation System): პლატფორმაზე განთავსდება მხარდაჭერის ღილაკი, რომელიც მომხმარებელს საშუალებას მისცემს, მცირე ფინანსური წვლილი შეიტანოს თავშესაფრის ფუნქციონირებაში. ინტეგრირებული იქნება გადახდის უსაფრთხო სისტემები (მაგ. PayPal ან საბანკო გადახდები), რაც პროექტს აქცევს თვითკმარ, სოციალურად ორიენტირებულ ტექნოლოგიურ გადაწყვეტად.
1. საზოგადოების ჩართულობა: ლაივ-სტრიმინგის ყურებისას მომხმარებელს უჩნდება ემოციური კავშირი ცხოველთან, რაც ზრდის დონაციის ალბათობას.


2. გამჭვირვალობა: როდესაც ადამიანი ხედავს, რომ ცხოველი თბილ თავშესაფარშია (ტემპერატურის სენსორის წყალობით) და მასზე ზრუნავენ, ნდობა სისტემის მიმართ იზრდება.
3. მდგრადობა: დონაციები დაეხმარება პროექტს ელექტროენერგიისა და სერვერის (Digital Ocean) ხარჯების დაფარვაში.

## ინდუსტრიული სტანდარტები

ამ თავში განხილულია ის საერთაშორისო ტექნიკური სტანდარტები და პროტოკოლები, რომლებსაც ეფუძნება პროექტის უსაფრთხო და ეფექტური მუშაობა.

ელექტრო და ელექტრონიკა (Electrical Engineering)

- IEEE 802.11 b/g/n: ეს სტანდარტი არეგულირებს უსადენო კავშირს Tapo C310 კამერასა და ლოკალურ ქსელს შორის. მისი დაცვა გარანტიას იძლევა, რომ 2K ვიდეო ნაკადი იქნება სტაბილური და თავსებადი სტანდარტულ როუტერებთან.
- IEC 62368-1: ვინაიდან სისტემა იყენებს სხვადასხვა ძაბვის წყაროებს (9V კამერისთვის და 12V გამათბობელი ელემენტისთვის), ეს სტანდარტი უზრუნველყოფს კვების ბლოკების და გაყვანილობის უსაფრთხო გამიჯვნას. იგი განსაზღვრავს კრიტერიუმებს ელექტრონული კომპონენტების დაცვისა და თერმული გადახურების პრევენციისთვის.
- AWG (American Wire Gauge) Standard: გამოიყენება სადენების კვეთის სწორად შესარჩევად 12V/8A დატვირთვის პირობებში, რათა თავიდან იქნას აცილებული გამტარების გადახურება და ძაბვის ვარდნა.

ჩაშენებული სისტემები და IoT (Embedded Systems & IoT)

- ARM CMSIS (Cortex Microcontroller Software Interface Standard): STM32L4 მიკროკონტროლერის პროგრამული უზრუნველყოფა შემუშავებულია ამ სტანდარტიზებული ინტერფეისით. ეს ახდენს წარმადობის ოპტიმიზაციას და უზრუნველყოფს სენსორების (AM2302, VL53L0X) დრაივერების მდგრადობას.
- I2C Bus Standard: კომუნიკაცია VL53L0X (Time-of-Flight) სენსორსა და მიკროკონტროლერს შორის მიჰყვება ამ ინდუსტრიულ პროტოკოლს, რაც უზრუნველყოფს მონაცემთა მაღალი სიჩქარითა და შეცდომების გარეშე გაცვლას რეალურ დროში.
- UART (Universal Asynchronous Receiver-Transmitter) Standard: ეს პროტოკოლი გამოიყენება STM32-სა და SIM800C მოდემს შორის მონაცემთა მიმოცვლისთვის. იგი უზრუნველყოფს საიმედო სერიულ კომუნიკაციას AT-ბრძანებების გადასაცემად, რაც აუცილებელია GPRS ქსელში მონაცემების გასაგზავნად.
- ISO/IEC 27001: ინფორმაციული უსაფრთხოების ამ პრინციპების დაცვით ხდება ვიდეო ნაკადისა და მართვის ბრძანებების კონფიდენციალურობის უზრუნველყოფა, 128-ბიტიანი AES დაშიფვრისა და SSL/TLS პროტოკოლების გამოყენებით.

პროგრამული ინჟინერია (Software Engineering)

- REST არქიტექტურული პრინციპები: Go-ზე დაფუძნებული Backend დაპროექტებულია როგორც RESTful API. ეს უზრუნველყოფს მონაცემთა დამუშავების შრის მკვეთრ გამიჯვნას ინტერფეისისგან, რაც სისტემას ხდის მასშტაბირებადს და ადვილად მოსავლელს.
- POSIX: სერვერული გარემო (DigitalOcean Droplet) იყენებს Linux-ის ოპერაციული სისტემის ინტერფეისებს, რომლებიც შეესაბამება POSIX სტანდარტებს. ეს უზრუნველყოფს MediaMTX სერვისისა და Go ბინარული ფაილების საიმედო მუშაობას ღრუბლოვან გარემოში.

ქსელები და კომუნიკაცია (Networking)

- RFC 2326 (RTSP) და RFC 8829 (WebRTC): ეს ინტერნეტ-სტანდარტები (IETF) წარმოადგენს ვიდეო დისტრიბუციის სისტემის საფუძველს. RTSP გამოიყენება ნაკადის მისაღებად, ხოლო WebRTC უზრუნველყოფს წამზე ნაკლებ დაყოვნებას ბრაუზერში ვიდეოს ჩვენებისას.
- IEEE 1588 (Precision Time Protocol): ეს სტანდარტი რელევანტურია AM2302 სენსორის მონაცემებისა და ვიდეო კადრების დროში სინქრონიზაციისთვის. ეს გარანტიას იძლევა, რომ მონიტორინგის პანელზე გამოსახული ტემპერატურა ზუსტად შეესაბამება ვიდეოზე ასახულ მომენტს.

## განტის დიაგრამა


იხილეთ ექსელის ფაილი (https://github.com/Kajutrs/Smart-Shelter-Project/blob/main/GhantChartwithMilestones.xlsx)

მოვალეობები

მოვალეობები | სტუდენტები
STM32L4 მიკროკონტროლერის დაპროგრამება | თამარ ჯაში
ToF და DHT22 სენსორების ინტეგრაცია | თამარ ჯაში
კომუნიკაციის მოდულის (SIM800C) გამართვა | თამარ ჯაში
თავშესაფრის ფიზიკური აწყობა | მარი დავლაძე
გათბობის ფენის ინსტალაცია | მარი დავლაძე
ელექტრონიკის დაცული განყოფილების მოწყობა | მარი დავლაძე
Tapo კამერის ქსელური კონფიგურაცია | გრიშა ტონერიანი
Backend API-ს დაწერა | გრიშა ტონერიანი
Frontend ინტერფეისის აწყობა | თამარ ჯაში
Digital Ocean სერვერის მომზადება | გრიშა ტონერიანი

იხილეთ ექსელის ფაილი (https://github.com/Kajutrs/Smart-Shelter-Project/blob/main/%E1%83%94%E1%83%A5%E1%83%A1%E1%83%94%E1%83%9A%E1%83%98%E1%83%A1%20%E1%83%A4%E1%83%90%E1%83%98%E1%83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)

## ბიუჯეტი

მოწყობილობა | რაოდენობა | ფასი(ლარი) | ჯამური ფასი(ლარი) | მაღაზია
STM32L476RG | 1 | 80.55ლარი | 116.79 ლარი | Amazon
VL53L0X ToF | 1 | 15.62ლარი | 15.62 ლარი | Temu
DHT22 | 1 | 2.21 ლარი | 3.69 ლარი | AliExpress
SIM800C GSM | 1 | 42.18 ლარი | 76.92 ლარი | Amazon

TapoC310 კამერა | 1 | 169 ლარი | 169 ლარი | ალტა/Alta
ადაპტერი 12V 10A | 1 | 32.32 ლარი | 71.21 ლარი | Amazon
IP65 | 1 | 18.57 ლარი | 57.10 ლარი | Amazon
გათბობის ფირი 12V | 1 | 12.51 ლარი | 25.02 ლარი | Alibaba
Step-down კონვერტორი (ძაბვისთვის) | 1 | 5.31 ლარი | 9.29 ლარი | AliExpress
რელე DC DC SSR | 1 | 6.74 ლარი | 25.01 ლარი | AliExpress
Digital Ocean სერვერი | 1 | 15.99 ლარი | 15.99 ლარი | Digital Ocean
FSF ფანერა (გარე) 2440×1220×12 მმ | 2 | 82,60 ლარი | 82,60 ლარი | დომინო
ექსტრუდირებული პოლისტიროლი XPS(შუა ფენა) | 1 შეკვრა | 63 ლარი | 63 ლარი | ნოვა
FK ფანერა(შიდა) 2440×1220 9 მმ | 2 | 14 ლარი | 28 ლარი | Proton
სილიკონი ტემპერატურაგამძლე | 1 | 18 ლარი | 18 ლარი | ნოვა
ჯამპერების პაკეტი | 1 შეკვრა | 2.08 ლარი | 2.92 ლარი | AliExpress
ბრედბორდი | 1 | 5.63 ლარი | 7.11 ლარი | AliExpress
რეზისტორები | 1 შეკვრა | 2.67 ლარი | 9.73 ლარი | AliExpress
ტრანზისტორები | 1 შეკვრა | 10.31 ლარი | 13.82 ლარი | Ebay

იხილეთ ექსელის ფაილი (https://github.com/Kajutrs/Smart-Shelter-Project/blob/main/%E1%83%94%E1%83%A5%E1%83%A1%E1%83%94%E1%83%9A%E1%83%98%E1%83%A1%20%E1%83%A4%E1%83%90%E1%83%98%E1%83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)

## ლიტერატურა

[1] STMicroelectronics, "STM32L476xx Ultra-low-power Arm® Cortex®-M4 32-bit MCU+FPU Datasheet," Rev. 4, 2023. [Online]. Available:

STM32L476xx Datasheet (https://www.st.com/resource/en/datasheet/stm32l476je.pdf)

[2] STMicroelectronics, "VL53L0X Time-of-Flight ranging sensor product datasheet," 2018. [Online]. Available:

VL53L0X Time-of-Flight Datasheet (https://www.st.com/resource/en/datasheet/vl53l0x.pdf)

[3] TP-Link Corporation, "Tapo C310 V2 (2.20, 2.26, 2.28) Outdoor Security Wi-Fi Camera Datasheet," 2023. [Online]. Available:

Tapo C310 V2 Wi - Fi Camera Datasheet (https://static.tp-link.com/upload/product-overview/2024/202403/20240319/Tapo%20C310%202.0&2.20&2.26&2.28_Datasheet.pdf)

[4] MediaMTX Project, "MediaMTX: Open-source Video Streaming Server Documentation," 2024. [Online]. Available:

Media MTX Documentation (https://github.com/bluenviron/mediamtx)

[5] Aosong Electronics Co., Ltd, "AM2302 Product Manual - Temperature and humidity module," [Online].

HDT22(AM2302) Manual (https://dfimg.dfrobot.com/enshop/image/data/SEN0137/AM2302_manual.pdf)

[6] Espressif Systems. (2015). ESP8266EX Datasheet (Version 4.3). Retrieved from Espressif Systems IOT Team.

ESP8266EX Datasheet (https://github.com/MadeByBalaji/NodeMCU/blob/main/ESP8266-NodeMCU-Datasheet.pdf)

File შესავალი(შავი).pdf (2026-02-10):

თბილისში, ზამთრის სეზონზე, უამრავი მიუსაფარი ცხოველი არის დაუცველი სიცივისგან. არესბობს რაღაც გადაწყვეტები, მაგალითად ცხოველთა თავშესაფრები ან ადამიანები, რომლებსაც გული შესტკივათ ცხოველებზე ქალაქის მასშტაბით დგამენ ხის ან მუყაოს კონსტრუქციებს რომ გათბობით უზრუნველყონ მიუსაფრები. სამწუხაროდ, მსგავსი გადაწყვეტები არ არის საკმარისი, რადგან აქტიური გათბობის გარეშე, თავშესაფრის შიდა ტემპერატურა მალე გაუთანაბრდება გარე ტემპერატურას. აქტიური გათბობის დანერგვის შემთხვევაში კი, გათბობა არ უნდა იყოს მუდმივად ჩართული და არ უნდა დაიკარგოს ელექტროენერგია ცარიელ სივრცეზე. ასევე პრობლემაა სანდო საქველმოქმედო საშუალებების არარსებობა. ადამიანები, რომელთაც ცხოველებზე შესტკივათ გული, ხშირად ცდილობენ დაეხმარონ და თანხა გადაურიცხონ ცხოველისთვის თავშესაფრის შექმნის ინიციატორს. სამწუხაროდ, მსგავს შემთხვევებში მათ უნდობლობა აფერხებთ რომ თამამად გადარიცხონ თანხა, ან გადარიცხვის შემდეგ შედეგის ნახვა რომ არ შეუძლიათ ეკარგებათ მოტივაცია რომ მომავალშიც დაეხმარონ მსგავს მოხალისეებს. ამიტომ, ჩვენ გვინდა შევქმნათ ისეთი სისტემა, რომელიც არ დახარჯავს რესურსებს ცარიელ სივრცეზე და ეკონომიურად მოიხმარს ელექტროენერგიას. ასევე, ჩვენი მისიაა შევქმნათ ისეთი თავშესაფარი რომლიც ადამიანის ჩარევის გარეშე თავად მიიღებს გადაწყვეტილებას და ჩართავს/გამორთავს გათბობას. ასევე, გვინდა დავნერგოთ მონიტორინგი, გვექნება კამერა, რომლიც გადაიღებს მუდმივ ვიდეო ნაკადს და ატვირთავს სერვერზე, შესაბამისად ნაკადი ხელმისაწვდომი იქნება ვებსაიტზე, სადაც ადამიანებს შეეძლებათ ნახონ თავშესაფარი რეალურ დროში და უფრო დიდი ნდობა და მოტივაცია ექნებათ გაიღონ ქველმოქმედება. მათ ექნებათ საშუალება ნახონ თავიანთი წვლილის შედეგი. გამოვიყენებთ STM32L4 მიკროკონტროლერს, რომელიც არის ენერგოეფექტური გადაწყვეტა, რადგან მას აქვს Stop რეჟიმები, სადაც ნაკლებ ენეგიას მოიხმარს. გამოვიყენებთ ToF მანძილის სენსორს, DHT22 ტემპერატურის სენსორს და TapoC310 კამერას, რომელიც სერვერზე აგზავნის ვიდეო ნაკადს RTSP პროტოკოლით. ამ პროტოკოლს WebRTC ფორმტად გარდაქმნის MediaMTX სერვერი, რაც არის დაბალი დაყოვნების ფორმატი, რომელიც აღქმადია ვებში.

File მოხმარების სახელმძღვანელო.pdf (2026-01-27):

# ჭკვიანი თავშესაფარი

## მოხმარების სახელმძღვანელო (User Manual)

# 1. შესავალი

„ჭკვიანი თავშესაფარი“ არის ავტომატიზებული IoT სისტემა, რომელიც შექმნილია უპატრონო ცხოველებისთვის უსაფრთხო, თბილი და ენერგოეფექტური გარემოს უზრუნველსაყოფად. სისტემა დამოუკიდებლად ამოიცნობს ცხოველის არსებობას, აკონტროლებს შიდა ტემპერატურას, საჭიროების შემთხვევაში რთავს გათბობას და მომხმარებელს აძლევს დისტანციური მონიტორინგის შესაძლებლობას.

# 2. სისტემის შემადგენლობა

ჭკვიანი თავშესაფარი შედგება შემდეგი ძირითადი კომპონენტებისგან:

- ფიზიკური კონსტრუქცია
თბოიზოლირებული კედლები, იატაკი და ჭერი (XPS იზოლაცია + ფანერა)
- ცენტრალური მართვის ბლოკი
STM32L476RG მიკროკონტროლერი
- სენსორები
1. VL53L0X ToF მანძილის სენსორი (ცხოველის აღმოჩენა)
2. DHT22 ტემპერატურისა და ტენიანობის სენსორი
- გათბობის სისტემა
1. 12V გამათბობელი ელემენტი
2. რელე გათბობის ჩართვა/გამორთვისთვის

- კომუნიკაცია
1. SIM800C GSM/GPRS მოდული (ტელემეტრიის გაგზავნა)
- ვიდეო მონიტორინგი
1. Tapo IP კამერა (RTSP → WebRTC)
- ვებ-პლატფორმა
1. Live ვიდეო
2. ტემპერატურის ჩვენება
3. დონაციის სისტემა

# 3. კვების მიწოდება

1. შეაერთეთ 12V / 10A ადაპტერი თავშესაფრის კვების პორტში.
2. დარწმუნდით, რომ ადაპტერი დაცულია ნესტისა და პირდაპირი თოვლისგან.
3. ჩართვის შემდეგ სისტემა ავტომატურად იწყებს ინიციალიზაციას.

# 4. მუშაობის პრინციპი

### 4.1 ცხოველის აღმოჩენა

- VL53L0X სენსორი მუდმივად ზომავს მანძილს.
- თუ დაფიქსირებული მანძილი 70 სმ-ზე ნაკლებია, სისტემა ასკვნის, რომ თავშესაფარში ცხოველია.

### 4.2 ტემპერატურის კონტროლი

- DHT22 სენსორი ზომავს შიდა ტემპერატურას.

- სამუშაო ლოგიკა:
1. < 18°C → გათბობა ირთვება
2. 18°C – 25°C → ტემპერატურა ნორმაშია
3. ≥ 25°C → გათბობა ითიშება

# 5. დისტანციური მონიტორინგი

### 5.1 ვებ-პლატფორმაზე წვდომა

მომხმარებელს შეუძლია ვებ-გვერდზე ნახოს:

- ლაივ ვიდეო ნაკადი თავშესაფრიდან
- მიმდინარე შიდა ტემპერატურა
- სისტემის სტატუსი (აქტიური / პასიური)

ვიდეო გადადის WebRTC ტექნოლოგიით, რაც ნიშნავს დაბალ დაყოვნებას და ბრაუზერში პირდაპირ გაშვებას.

# 6. მონაცემების გადაცემა

- სენსორული მონაცემები იგზავნება GSM ქსელის საშუალებით.
- მონაცემები ფორმირდება JSON პაკეტად და იგზავნება HTTP POST მოთხოვნით.
- სერვერი მონაცემებს ინახავს და აჩვენებს Dashboard-ზე.

თუ ინტერნეტი დროებით გაითიშა, სისტემა ადგილზე მაინც აგრძელებს მუშაობას. ინტელექტი არ არის მთლიანად ღრუბელზე მიბმული.

# 7. დონაციის სისტემა

ვებ-პლატფორმაზე განთავსებულია მხარდაჭერის ღილაკი, რომელიც მომხმარებელს საშუალებას აძლევს:

- შეიტანოს ფინანსური წვლილი
- დაეხმაროს თავშესაფრის ენერგიისა და სერვერის ხარჯების დაფარვაში
- რეალურად დაინახოს, სად მიდის მისი დახმარება

# 8. უსაფრთხოების მითითებები

- არ გახსნათ ელექტრონიკის განყოფილება მუშაობის დროს.
- არ შეცვალოთ კვების ადაპტერი არასტანდარტულით.
- არ დააზიანოთ სენსორების პოზიცია თავშესაფრის შიგნით.
- კამერის კვება ყოველთვის უნდა იყოს დამოუკიდებელი.

# 9. ტექნიკური მოვლა

- რეკომენდებულია თვეში ერთხელ:
1. კამერის ლინზის გაწმენდა
2. თავშესაფრის შიდა სივრცის დათვალიერება
- პროგრამული განახლება ხდება სერვერის მხრიდან და მომხმარებლის ჩარევას არ საჭიროებს.

# 10. შეჯამება

ჭკვიანი თავშესაფარი არის:

- ენერგოეფექტური
- ავტონომიური
- უსაფრთხო
- გამჭვირვალე

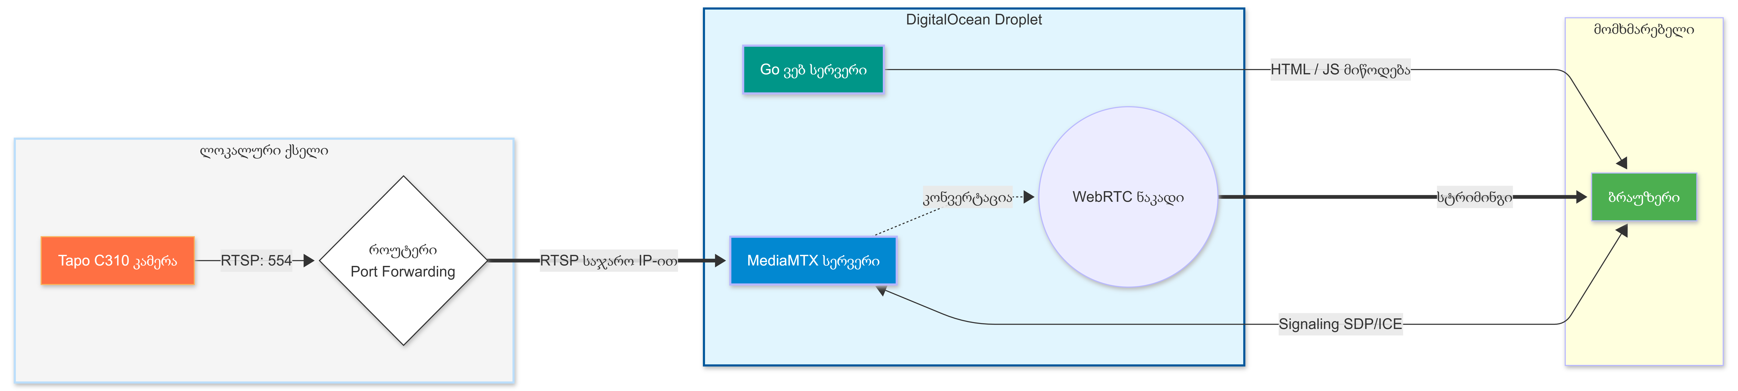
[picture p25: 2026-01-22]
ნახაზები/RTSP ნაკადის გადაცემა.png

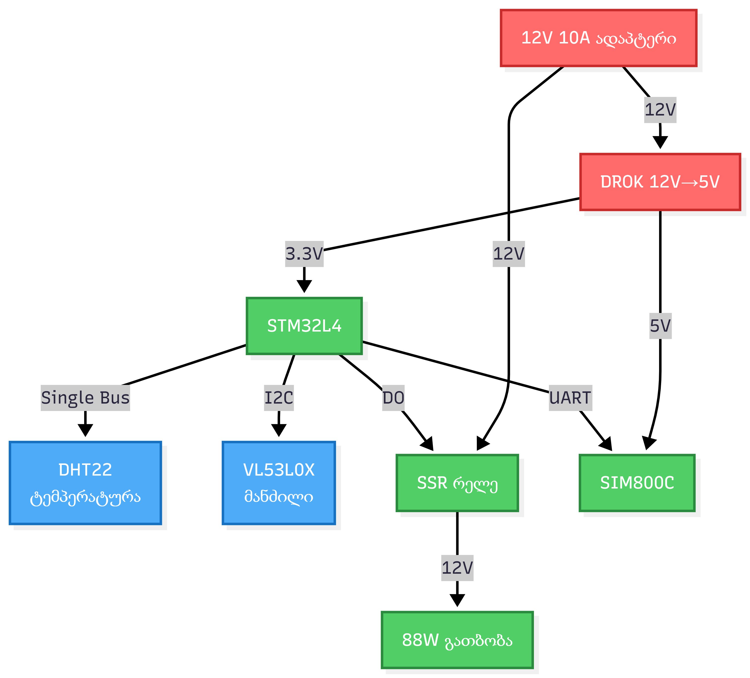
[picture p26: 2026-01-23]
ნახაზები/ელექტრული სქემა (გათბობის წრედი).png

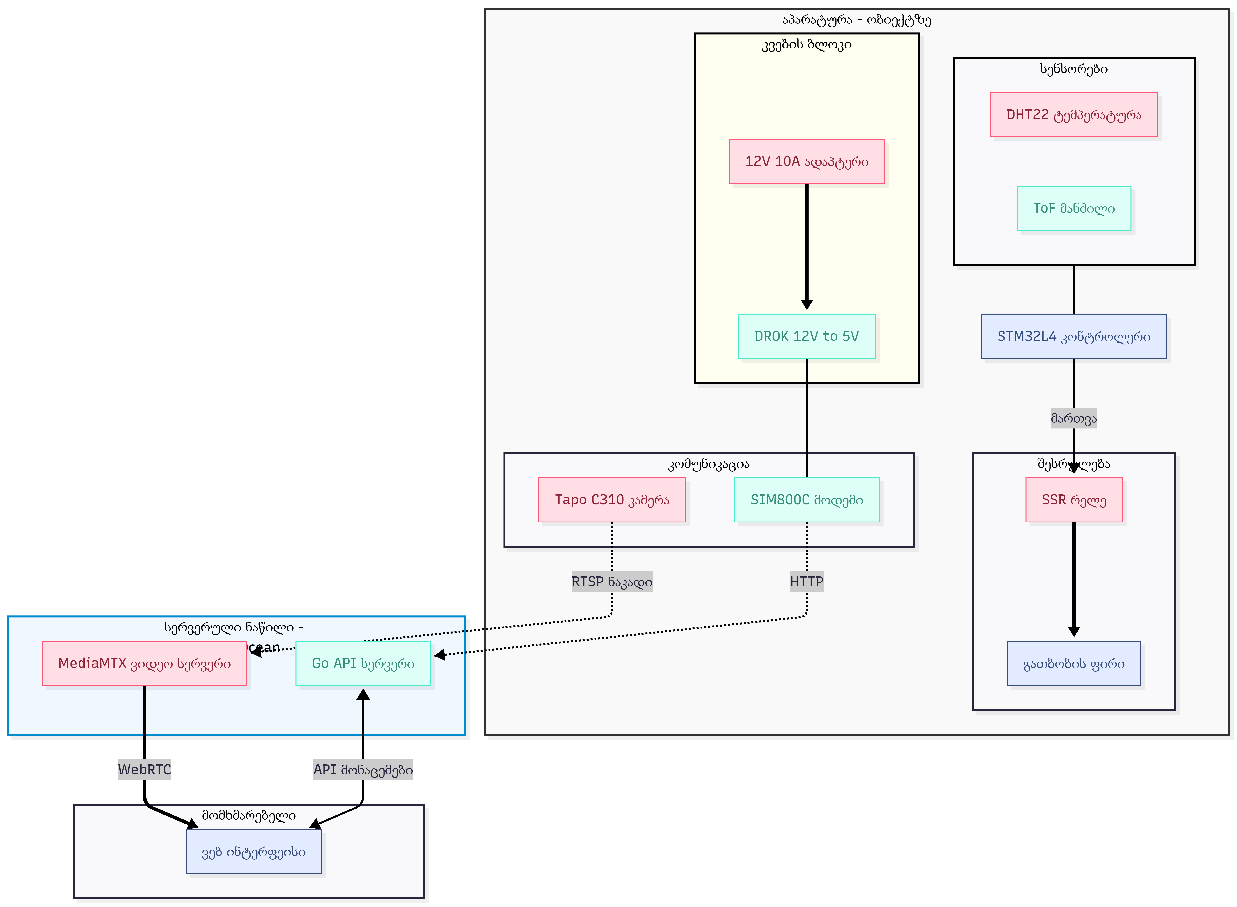
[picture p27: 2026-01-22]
ნახაზები/სისტემის ფუნქციური დიაგრამა.png

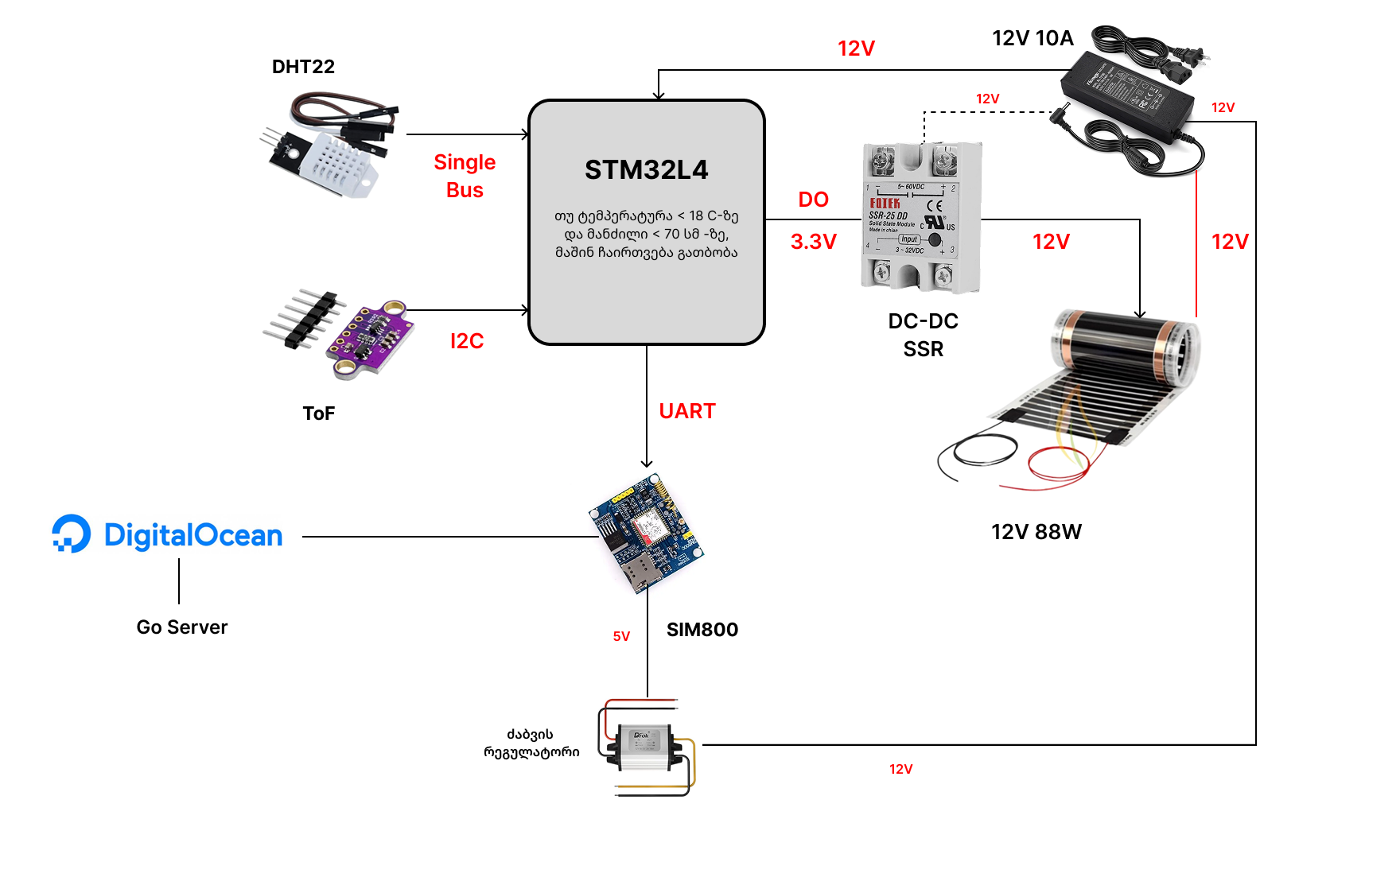
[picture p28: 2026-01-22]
ნახაზები/კილიმატ - კონტროლისა და სენსორული მართვის ბლოკსქემა.png

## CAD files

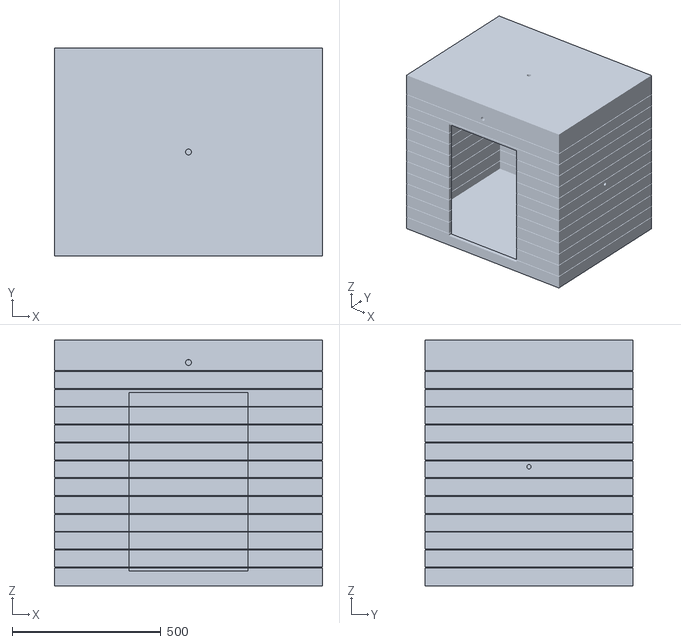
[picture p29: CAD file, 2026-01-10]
ნახაზები/კონსტრუქცია 3D.stl
900.0 x 700.0 x 825.0

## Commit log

2026-01-10 Create main.c
    კოდი წარმოადგენს ჭკვიანი თავშესაფრის (Smart Shelter) ცენტრალურ პროგრამულ უზრუნველყოფას, რომელიც რეალიზებულია STM32L476RG მიკროკონტროლერზე. სისტემის მთავარი დანიშნულებაა ცხოველებისთვის ოპტიმალური კლიმ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
    იმპლემენტაცი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
2026-01-10 Create server.go
    ოპტიმიზირებული მონაცემთა სტრუქტურა: სერვერი ამუშავებს მხოლოდ კრიტიკულ ინფორმაციას: გარემო ტემპერატურას (Temp), მანძილს ცხოველამდე (Distance) და გათბობის რელეს სტატუსს (Heating).
    მსუბუქი პროტოკოლი: იყენებს HTTP POST მეთოდს JSON ფორმატის მონაცემების მისაღებად, რაც უზრუნველყოფს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
2026-01-11 Create Tapo C310 ვიდეო ნაკადი (RTSP)
    კამერის ნაკადის მისაღებად გამოიყენება RTSP პროტოკოლი. ბმულის ფორმატი შემდეგია:
2026-01-11 Create Backend სერვერი და Dashboard (Go)
    ეს არის Go-ს კოდი, რომელიც ჰოსტავს ვებსაიტს (Dashboard), იღებს მონაცემებს და აჩვენებს კამერის ნაკადს
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2026-01-11 Create Data Transmission Snippet
    ეს კოდი აჩვენებს, როგორ "ელაპარაკება" STM32 WiFi მოდულს (ESP-01), რათა მონაცემები სერვერზე გაიგზავნოს.
2026-01-11 Create Go Server Handler (Go)
    ეს კოდი გაშვებულია სერვერზე და იღებს STM32-დან გამოგზავნილ ინფორმაციას.
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2026-01-11 Add files via upload
    მოცემულია კომპონენტების ჩამონათვალი და ფასები.
    [მოწყობილობების_ცხრილი ექსელი.xlsx]
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2026-01-21 Add files via upload
    1. სისტემა ყოველ 10 წამში ერთხელ ამოწმებს, არის თუ არა ვინმე თავშესაფარში და რა ტემპერატურაა შიგნით.
    2. გათბობა მხოლოდ მაშინ ირთვება, როცა ცხოველი შიგნითაა და 18 გრადუსზე ნაკლებია ტემპერატურა. როგორც კი ჰაერი 25 გრადუსამდე გათბება, სისტემა თავისით ითიშება, რომ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
2026-01-21 Add files via upload
    „ჭკვიანი თავშესაფარი“ მუშაობს DHT22 და ToF სენსორების მეშვეობით, რომლებიც მუდმივად აკონტროლებენ ტემპერატურას თავშესაფრის შიგნით და ადასტურებენ ცხოველის შიგნით ყოფნა/არ ყოფნას. სისტემას სითბოთი უზრუნვ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
2026-01-22 Add files via upload
    კლიმატ-კონტროლისა და სენსორული მართვის ბლოკსქემა წარმოადგენს „ჭკვიანი თავშესაფრის“ ავტონომიურ აპარატურულ არქიტექტურას, რომელიც პასუხისმგებელია გარემო პირობების მონიტორინგზე, ენერგოეფექტურ გათბობასა დ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
2026-01-22 Add files via upload
    ეს პროექტი აჩვენებს, თუ როგორ შეიძლება Tapo C310 კამერის RTSP ნაკადის გარდაქმნა WebRTC‑ზე MediaMTX - ის გამოყენებით, რათა მომხმარებელს ჰქონდეს პირდაპირი წვდომა ბრაუზერიდან.
2026-01-22 Add files via upload
    დიაგრამაზე ნაჩვენებია მონაცემთა ორი პარალელური ნაკადი: სენსორული მაჩვენებლების გადაცემა STM32 კონტროლერიდან SIM800C მოდემის (GPRS) გავლით Go სერვერზე და ვიდეო სტრიმინგი Tapo კამერიდან MediaMTX-ის მეშ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
2026-01-22 Add files via upload
    ეს დიაგრამა აღწერს, თუ როგორ ხდება ვიდეოს გაგზავნა კამერიდან ბრაუზერამდე. სისტემის მთავარი რგოლია MediaMTX სერვერი, რომელიც მუშაობს როგორც RTSP პროტოკოლის WebRTC პროტოკოლად გადამყვანი. ის იღებს ვიდეო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
2026-01-22 Rename Construction.stl to კონსტრუქცია 3D.stl
    [კონსტრუქცია 3D.stl]
2026-01-22 Rename მოწყობილობების_ცხრილი ექსელი (1).xlsx to კომპონენტები/ბიუჯეტი.xlsx
    [ბიუჯეტი.xlsx]
2026-01-23 Add files via upload
    ეს დიაგრამა წარმოადგენს პროექტის გათბობის სისტემის გამარტივებულ სქემას და განსაზღვრავს, როგორ ხდება კვების განაწილება, სენსორული მონაცემების შეგროვება, აქტუატორების მართვა და უკაბელო კომუნიკაცია ერთი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
2026-01-25 Rename კომპონენტები და ბიუჯეტი.xlsx to ექსელის ფაილები/კომპონენტები და ბიუჯეტი.xlsx
    [კომპონენტები და ბიუჯეტი.xlsx]
2026-01-25 Rename GhantChartwithMilestones.xlsx to ექსელის ფაილები/GhantChartwithMilestones.xlsx
    [GhantChartwithMilestones.xlsx]
2026-01-25 Rename GhantChartwithMilestones.xlsx to განტის დიაგრამა.xlsx
    [განტის დიაგრამა.xlsx]
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2026-01-25 Rename კილიმატ - კონტროლისა და სენსორული მართვის ბლოკსქემა.png to კილიმატ - კონტროლისა და სენსორული მართვის ბლოკსქემა.png
2026-01-25 Rename კონსტრუქცია 3D.stl to კონსტრუქცია 3D.stl
    [კონსტრუქცია 3D.stl]
2026-01-25 Rename სისტემის მართვისა და მონაცემთა გადაცემის ალგორითმი.png to სისტემის მართვისა და მონაცემთა გადაცემის ალგორითმი.png
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2026-01-25 Rename Backend სერვერი და Dashboard (Go) to Backend სერვერი და Dashboard (Go)
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2026-01-25 Rename Tapo C310 ვიდეო ნაკადი (RTSP) to Tapo C310 ვიდეო ნაკადი (RTSP)
2026-01-25 Rename Data Transmission Snippet to SIM800C-ის მეშვეობით ტელემეტრიული მონაცემების HTTP POST გაგზავნა
2026-01-25 Rename SIM800C-ის მეშვეობით ტელემეტრიული მონაცემების HTTP POST გაგზავნა to SIM800C-ის მეშვეობით ტელემეტრიული მონაცემების გაგზავნა
2026-01-25 Rename Backend სერვერი და Dashboard (Go) to დაშბორდის მართვისა და მონაცემთა ინტეგრაციის ლოგიკა
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2026-01-25 Rename main.c to ჭკვიანი თავშესაფრის ცენტრალური მართვის ალგორითმი
    ეს კოდი წარმოადგენს სისტემის ინტელექტუალურ ბირთვს, რომელიც მუშაობს STM32L476RG მიკროკონტროლერზე. მისი მუშაობა დაყოფილია სამ ფაზად: (1) ინიციალიზაცია და კავშირის დამყარება - სენსორების, GSM მოდულის და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
2026-01-26 Add files via upload
    მოცემულია ცხრილი, სადაც ჯგუფის თითოეულ წევრს აქვს მინიჭებული შესაბამისი დავალება შემდეგ სემესტრში განსახორციელებლად.
    [მოვალეობები.xlsx]
2026-01-26 Add files via upload
    ფაილში მოცემულია პროექტისთვის საჭირო კომპონენტების ჩამონათვალი, ლინკები, ფასები და ჯამური ფასი.
    [კომპონენტების ცხრილი და ბიუჯეტი.xlsx]
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
